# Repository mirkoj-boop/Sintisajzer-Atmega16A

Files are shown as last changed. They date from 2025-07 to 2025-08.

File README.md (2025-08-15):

# 🎹 Razvoj jednostavnog digitalno upravljanog sintisajzera temeljenog na mikroupravljaču ATmega16A

**** jednostavni PCB dizajn:
- **ATMEGA16-A** kao digitalni Oscilator
- an **LM386 preamplifier** pretpojačalo za 8 Ω zvučnik.

Dizajnirano jednostavno pojačalo za sintisajzer

1. Inicijaliziraj I2C komunikaciju
2. Inicijaliziraj tri MCP23008 čipa (postavi sve pinove kao ulaze)
3. Beskonačno ponavljaj:
   a. Pročitaj stanje tipki s prva tri MCP23008 čipa (8 tipki po čipu, ukupno 24)
   b. Inverzija očitanja (jer su tipke aktivne na LOW)
   c. Provjeri pritisnute tipke u sljedećem redoslijedu:
      - Za prvi čip (tipke 0-7):
        Ako je neka tipka pritisnuta, pošalji vrijednost note (notes[0-7]) na DAC i prekini
      - Ako nema pritisnutih tipki na prvom čipu, provjeri drugi čip (tipke 8-15):
        Ako je neka tipka pritisnuta26, pošalji vrijednost note (notes[8-15]) na DAC i prekini
      - Ako nema pritisnutih tipki na drugom čipu, provjeri treći čip (tipke 16-23):
        Ako je neka tipka pritisnuta, pošalji vrijednost note (notes[16-23]) na DAC i prekini
      - Ako nijedna tipka nije pritisnuta, postavi DAC na 0 (tišina)
   d. Pričekaj 10 ms prije sljedećeg očitavanja

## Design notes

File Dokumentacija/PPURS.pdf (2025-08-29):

### TEHNIČKO VELEUČILIŠTE U ZAGREBU

STRUČNI PRIJEDIPLOMSKI STUDIJ ELEKTROTEHNIKA

Mirko Jokić

# Razvoj jednostavnog digitalno upravljanog sintisajzera temeljenog na mikroupravljaču Atmega16A

Projektni Zadatak PPURS

Zagreb, Kolovoz 2025

## Sadržaj

Sadržaj
Uvod | 3
1.1 Odabir mikroupravljača za projektni zadatak | 4
2 Opis hardvera | 5
2.1 Implementacija predpojačala kroz LM386 | 6
2.2 MCP23008 I2C Port Expander | 7
2.3 1602 LCD 4-bitni ekran | 9
2.4 Kućište sinsajzera | 10
2.5 Troškovnik | 11
3 Programski Kod | 12
Zaključak | 13
Prilog | 14
Literatura | 20

Slike
Slika 1.1 Blok shema projekta | 3
Slika 2.1 Kicad shema MCP23008 24 pke | 5
Slika 2.2 Shema predpojačala | 6
Slika 2.4 Shema MCP23008 Port Expander | 7
Slika 2.5 PCB Editor shema 24 pke | 8
Slika 2.6 LCD ekran 4-bitno Serijski spojen | 9
Slika 2.7 Kućište Sinsajzera | 10
Slika 3 Flow Chart glavnog programskog koda | 12

Tablica
Tablica 1 Opis MCP23008 spojeva | 8
Tablica 2 Troškovnik | 11

## Uvod

Razvoj mikroupravljača i prateće digitalne elektronike omogućio je da se i složeni sustavi, poput glazbenih instrumenata, mogu realizirati jednostavno i pristupačno. Zahvaljujući svojoj fleksibilnosti, mogućnosti programiranja i količini opće programirljivih ulazno/izlazno jedinica na mikroupravljaču, omogućili smo jednostavnije projektiranje kopija modernih sintisajzera.
Naponski generiran oscilator i filter sada je lako zamijenjiv sa Digitalnim oscilatorom koji uzorkovanjem šalje signal analognom psintisajzera.
Cilj ovog rada je povezati digitalnu i analognu elektroniku kroz izradu jednostavnog digitalno upravljanog glazbenog sintisajzera. stav se temelji na mikroupravljaču Atmega16A-U, koji generira digitalne zapise tonova putem širinsko impulsne modulacije koji frekvencijskim odzivom preuzetim sa poljem koje sadrži tonove od C4 do B3 priprema za daljnu obradu.
Taj se signal dalje pojačava analognim pretpojačalom i dovodi na zvučnik. Ulazni sustav temelji se na tipkama povezanima preko I2C proširivača ulazno-izlaznih portova, čime se postiže jednostavan dizajn i omogućava korištenje većeg broja ulaza nego što ih mikroupravljač sam nudi.

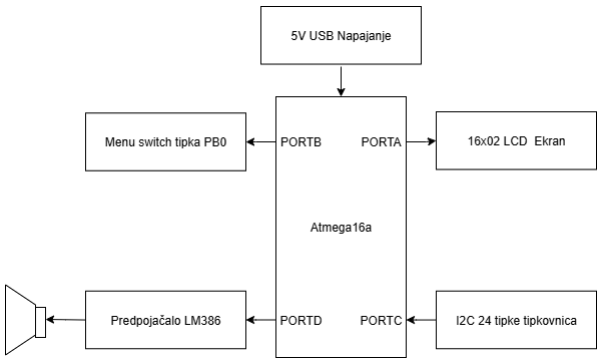
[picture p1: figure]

Slika 1.1 Blok shema projekta

## 1.1 Odabir mikroupravljača za projektni zadatak

Baza samog kontrolera je mikorupravljač Atmel ATMEGA 328-PU. Kontroler ima funkciju Digitalnog naponskog oscilatora koji stvara signal pripremljen za ostatak mreže. Opremljen je serijskom komunikacijom kojom je spušten C programski kod i kojim je naknadno spojen 1602 LCD module. Ostatak mreže napajan je I2C protokolom. Sam mikroupravljač spojen je 220V AC adapterom na 5V DC koji dijeli na ostatak komponen.

Prema prethodno izrađenom blok dijagramu, izrađena je električna shema kontrolera koja obuhvaća sve elemente potrebne za povezivanje senzora i aktuatora odnosno uređaja.
Kod dizajna tiskane pločice elementi se automatski iz sheme, prenose na tiskanu pločicu koji se ručno razmještaju prema potrebama s obzirom na izvedbu kućišta kontrolera. Sami dizajn osim što obuhvaća razmještaj komponenti i vodova, obuhvaća definiranje debljina vodova, razmake između vodova, definiranje Via između slojeva i rupa za montažu.

Tehnička specifikacija mikroupravljača Atmel ATmega16A-PU

- Arhitektura: 8-bitni RISC mikroupravljač
- Taktni generator: do 16 MHz (u ovom sustavu: 16 MHz kvarc)
- Radni napon: 2.7 V do 5.5 V (1.8 V – 5.5 V u „low frequency” načinu, do 8 MHz)
- Flash memorija: 16 KB (od čega do 512 B može bi rezervirano za bootloader)
- SRAM: 1 KB
- EEPROM: 512 B
- Ulazno-izlazni pinovi: 32 programabilna I/O pina
- ADC kanali: 8 (10-bitni A/D pretvarač)
- Komunikacija: UART, SPI, I²C (TWI)
- Timeri: dva 8-bitna i jedan 16-bitni mer
- Potrošnja: pično par mA u akvnom načinu rada, < 1 µA u power-down modu
- Paket: PDIP-40 (u ovom projektu)

## 2 Opis hardvera

Korisničko sučelje sintisajzera realizirano je pomoću 24 tipke na PCB ploči sa SMD komponentama projektirano u Kicad 9.0 programu. Za proširenje dostupnih ulaza spojena su 3 MCP23008 PORT Expander-a, putem I2C protokola. Ovom tehnikom omogućeno je najbrže komercijalno dostupno očitanje stanja svih tipki 100 kHZ.

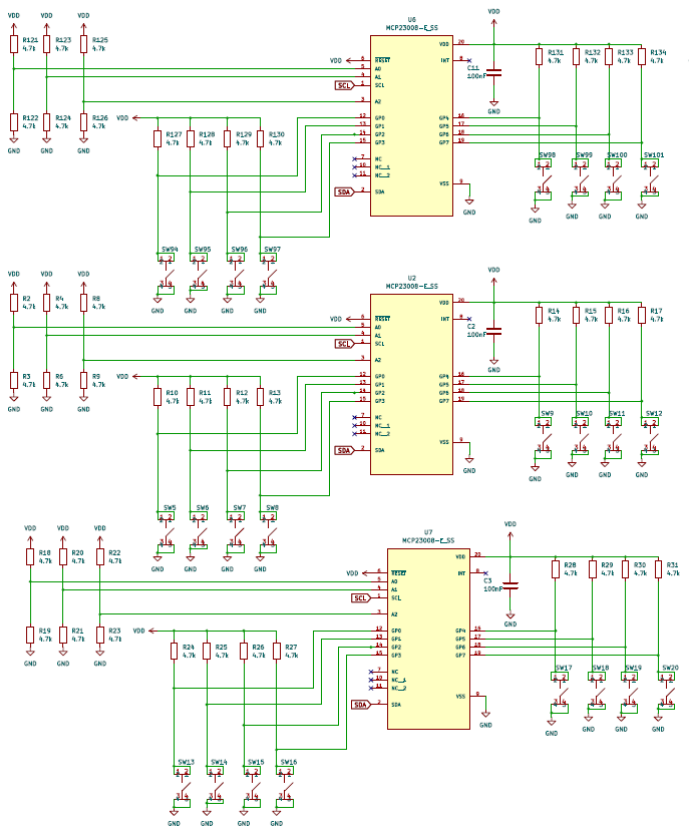
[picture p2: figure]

Slika 2.1 Kicad shema MCP23008 24 pke

### 2.1 Implementacija predpojačala kroz LM386

LM386 je predpojačalo klase AB dizajnirano za male izlazne snage. Interni Gain iznosi 20, a postavljen je 200, spajanjem elektrolitskog kondenzatora u vrijednosti od 10 µF, između pinova 1 i 8.
Ulazni pinovi mjere se u odnosu na masu, dakle referentan napon oko koje siječe audio signal je 0 V. Čip je napajan prema 5 V a referencu dobija sa Atmega16A PortD pina PD7, ispred kojeg je stavljen 10 KΩ potenciometar.

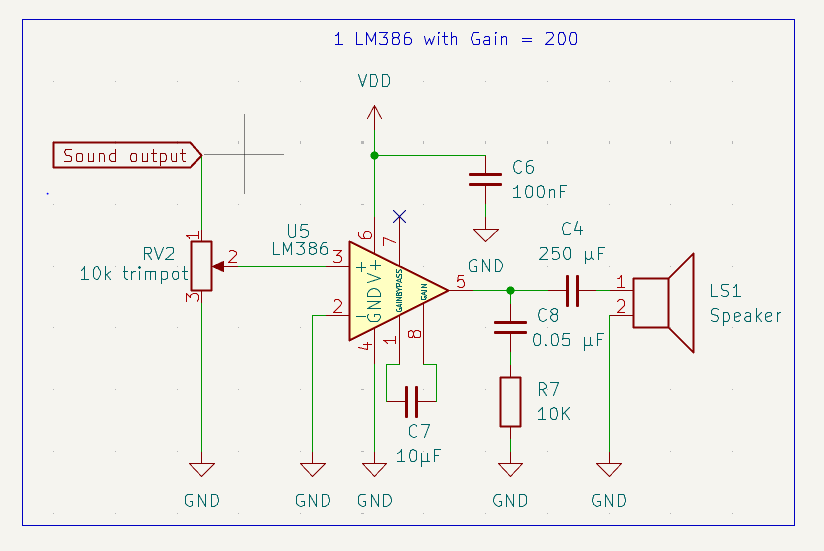
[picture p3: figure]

Slika 2.2 Shema predpojačala

Predpojačalo upravlja 8Ω zvučnikom snage 0.5 W, zbog čega je idealan za ovakve primjene zbog male potrošnje energije i dobrog omjera kvalitete pojačanog signala i učinkovitosti, bez značajnih gubitaka u struji i pregrijavanja komponente.

### 2.2 MCP23008 I2C Port Expander

MCP23008 je ekspanzijski sklop koji služi za proširenje broja ulazno/izlaznih jedinica mikrokontrolera koristeći I2C(TWI) sabirnicu. Sastoji se od 8 GPIO proširivih ulaza/izlaza i 3 adresna pina pomoću kojih se određuje adresa modula na sabirnici.

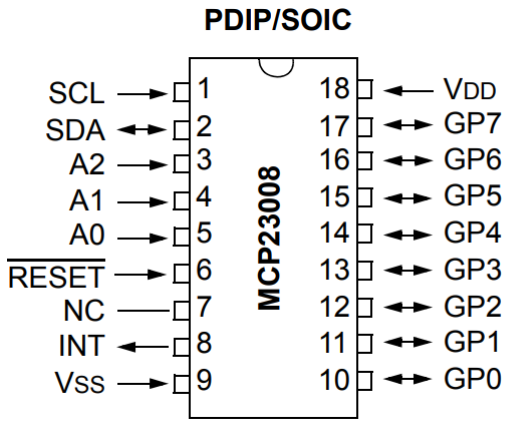
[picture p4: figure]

Slika Slika 24 .3Shema MCP23008 Port Expander Shema MCP23008 Port Expander

Pin | Naziv | Opis
1 | SCL | Takt
6 | RESET | Reset
9 | VSS | Napajanje
2 | SDA | Serijsko slanje podatka
7 | NC | Nema Konektora
3-5 | A1-A3 | Adresni pinovi
8 | INT | Interrupt izlaz
10-18 | GPIO | I/O tipka

Tablica 1 Opis MCP23008 spojeva

U praktičnoj primjeni često se preferira konfiguracija u kojoj su pinovi u visokom logičkom stanju (pull-up), a prelaze u nisko stanje (LOW) prilikom aktivacije tipke. Takva konfiguracija osigurava stabilniji rad i smanjuje osjetljivost sustava na elektromagnetske smetnje.
Master mikrokontroler ATMEGA16A komunicira s MCP23008 po vaki od triju adresnih pinova (A0–A2) može biti spojen na izvor napajanja (logička jedinica) ili na masu (logička nula) koju kasnije pomiče zavisno od čitanja/pisanja stanja. Na taj način moguće je formirati osam različitih adresa uređaja u rasponu od 0x20 do 0x27. U ovom projektu korištene su adrese 0x21, 0x22 i 0x23, što omogućuje spajanje i neovisno adresiranje triju MCP23008 modula na istoj I2C sabirnici.

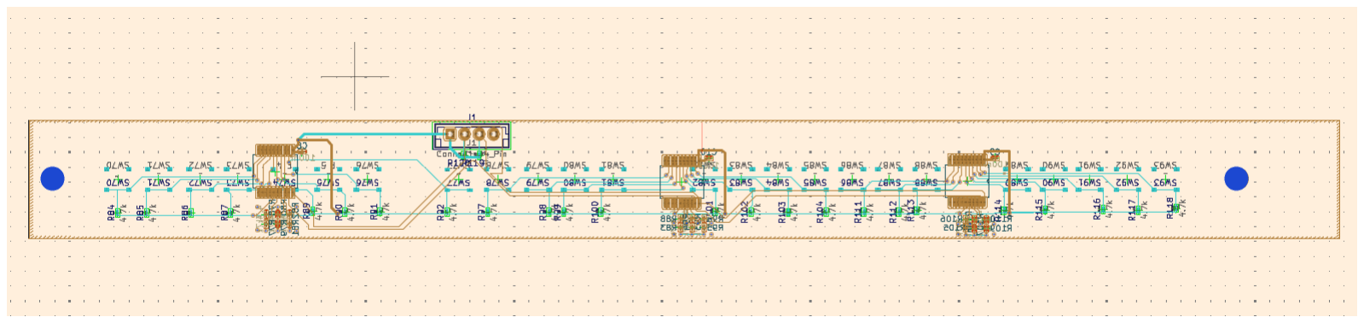
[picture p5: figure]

Slika 2.4 PCB Editor shema 24 pke

### 2.3 1602 LCD 4-bitni ekran

U projektu je korišten standardni LCD 16x2 zaslon temeljen na HD44780 kontroleru. Ovakav zaslon prikazuje 16 znakova u dva retka, a komunikacija je ostvarena u 4-bitnom načinu rada. U takvom načinu rada, podaci se šalju u dva dijela tzv. Nibble. Ponajprije se šalje viši, a zatim niži polubajt(Nibble). Važno je napomenuti kako u ovom načinu rada ekran je obavezno spojen D4- D7, a ne od početka(D0-D3) kako bi znao kontroler poslati 4-bitnu, a ne 8-bitnu komunikaciju. LCD zaslon analogno upravlja pozadinskim osvijetljenjemi osvijetljenjem znakova. Važno je stoga ispravno spojiti LED+ i LED-, tj, između obavezno postaviti otpornik, u ovom slučaju 560 Ω. Svijetlinu znakova regulira trimmer potenciometar 10 KΩ, odabran zbog veličine koja stane na pločicu.

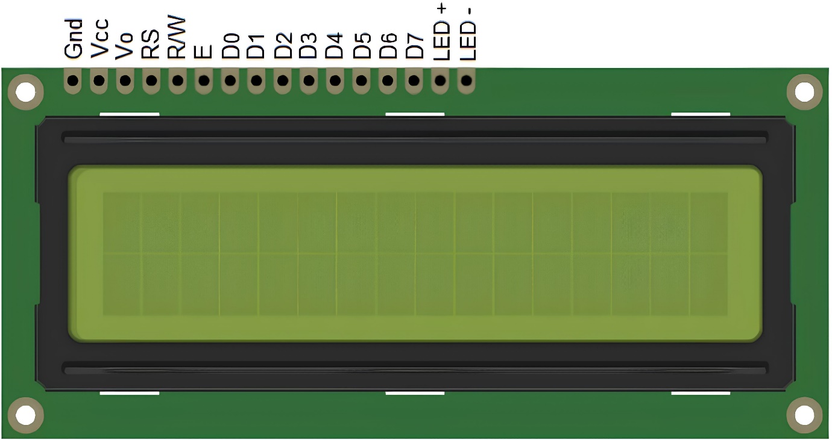
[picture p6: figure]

Slika 2.5 LCD ekran 4-bitno Serijski spojen

### 2.4 Kućište sinsajzera

Kućište uređaja prvo je osmišljeno i modelirano u programu AutoCAD 2025, a zam je prenijeto u SolidWorks 2020, gdje su izrađeni BOM (Bill of Materials) i STL datoteke potrebne za 3D ispis.

Za izradu kućišta korišten je 3D printer Bambu Lab X1 Carbon, a proces ispisa trajao je približno 4 sata. Materijal korišten za ispis bio je ASA filament (bijeli), odabran zbog svoje čvrstoće i otpornos na vanjske uvjete.

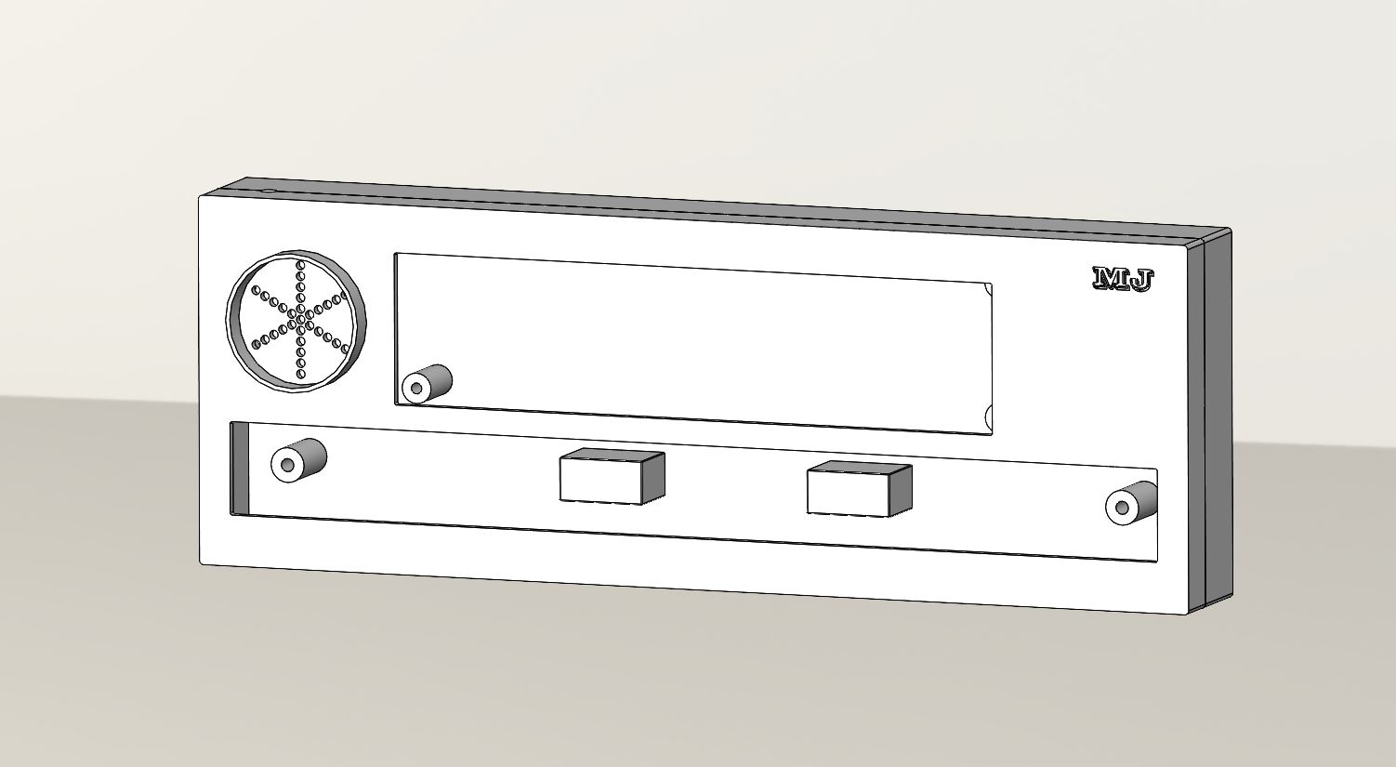
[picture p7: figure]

Slika 2.6 Kućište Sinsajzera

Prva iteracija imala je nekoliko problema:
- Poklopac je krivo isprintan i zvučnik se ne drži na mjestu
- Dimenzije su bile pogrešne, bio je predubok
- Donja strana je imala značajne deformacije

Konačna verzija kućišta pokazala se zadovoljavajuće kvalitete i funkcionalnos te estetski odgovara namjeni sinsajzera.

### 2.5 Troškovnik

Cijena uređaja sastoji se od maloprodajne cijene komponenti na tržištu i cijene izrade. Mjerni uređaji poput osciloskopa, lemilice, računala, 3d printera e računaju se u materijalne troškove, već se uračunavaju u cijenu uloženog rada.
Komponente | Cijena u €
Atmega16a | 2.85 €
LCD ekran | 3.15 €
PCB pločica | 39 €
Bijeli filament za 3d printer | 22.90 €
Tipke | 12.72 €
Lm386 | 1.31 €
Otpornici i kondenzatori | 1.30 €
Protoboard | 1.90 €
Ukupno | 85.13 €
Tablica 2 Troškovnik

Trošak izrade bez uračunah protopa iznosi 85.13 €, zajedno sa pokušajima i tesranjima prelazi 100 €.
Projekranje, izrada, narudžba i lemljenje iznosi 8 € po satu, za dva radna tjedna 8h rada = 640 €

## 3 Programski Kod

Programski kod napisan je u programskom okruženju Microchip studio. Razvojno okruženje omogućuje kvalitetan linker i toolchain #include <avr/io.h>. Taj header file definira sve registre i bitove potrebne za konfiguraciju i upravljanje svim protokolima i sučeljima koje se mogu ostvariti na Atmega mikroupravljaču.
Bez ovog zaglavlja, program ne bi mogao direktno pristupiti registrima i konfigurirati pinove ili periferije mikrokontrolera.
U glavnom programskom kodu Atmega16a poziva sve periferije sukladno dogovorenom protokolu. Rad je sastavljen od 3 protokola, one wire toggle za stanje tipke PB0, I2C za 24 tipke koje sviraju i 4 bitna serijska komunikacija za LCD ekran.
Sve to povezano je kroz header datoteke koje pozivaju funkcije objasnjene u sklodnim kodovima unutar istog projekta.

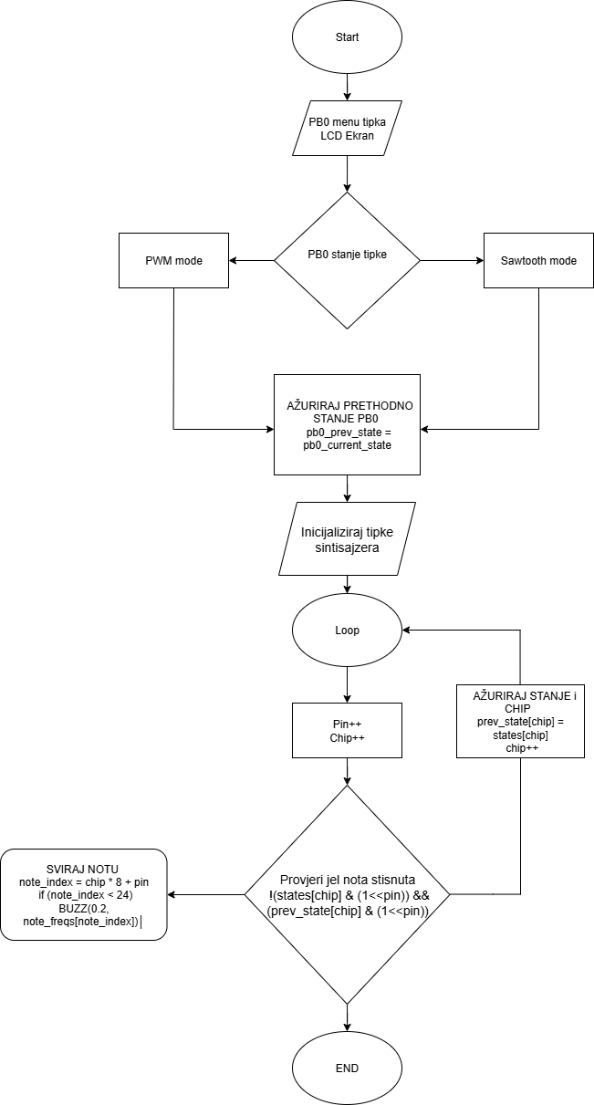
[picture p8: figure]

Slika 3 Flow Chart glavnog programskog koda

## Zaključak

U ovom projektnom zadatku uspješno je realiziran jednostavan digitalno upravljani sintisajzer temeljen na mikroupravljaču Atmega16A. Projekt je pokazao kako se kombinacijom digitalne i analogne elektronike može ostvariti funkcionalan glazbeni instrument pristupačne cijene i relativno jednostavne izvedbe.
Kroz implementaciju MCP23008 I2C port expandera omogućeno je proširenje broja ulaza te povezivanje 24 tipke, čime je ostvareno korisničko sučelje instrumenta. Generirani signal obrađen je i pojačan pomoću predpojačala temeljenog na LM386, a izlazni zvuk dobiven je putem zvučnika. Dodatno, korišten je LCD zaslon 16x2 za prikaz informacija, što doprinosi preglednosti sustava. Posebna pažnja posvećena je i mehaničkom dijelu – kućište je izrađeno 3D printanje, čime je postignuta funkcionalna i estetski prihvatljiva izvedba.
Projektu nedostaju brzina i sigurnost izvedbe. Sigurnost koda temeljena je na testiranju usart komunikacijom kojom je ostvaren predpregled nadolazećih funkcija I protokola.

Kao smjer budućeg razvoja, moguće je razmotriti promjenu mikroupravljača, kvalitetniji error check, više vizualnih signala i kvalitetnija izrada.

## Prilog

U prilogu se nalazi main kod programa i električne sheme sklopa

### include "AVR lib/AVR_lib.h" #include <avr/io.h> #include <util/delay.h> #include "I2C/i2c.h" #include "LCD/lcd.h" #define MCP23008_ADDR1 0x21 #define MCP23008_ADDR2 0x22 #define MCP23008_ADDR3 0x23

### #define IODIR 0x00

#define GPPU | 0x06 // Pull-up registar

#define GPIO | 0x09

### static const int note_freqs[24] = {

262, 277, 294, 311, 330, 349, 370, 392, 415, 440, 466, 494,

### // C4 do B4

523, 554, 587, 622, 659, 698, 740, 784, 831, 880, 932, 988

### // C5 do B5

};

uint8_t display_mode = 0;
uint8_t pb0_prev_state = 1;

### void mcp23008_init(uint8_t addr)

{
uint8_t write_addr = addr << 1;

### if (i2c_start(write_addr) != 0) {

return;
}
i2c_write(IODIR);
i2c_write(0xFF);
i2c_stop();
if (i2c_start(write_addr) != 0) return; i2c_write(GPPU);
i2c_write(0xFF);
i2c_stop();
}

### uint8_t mcp23008_read(uint8_t addr) {

uint8_t write_addr = addr << 1;
uint8_t read_addr = write_addr | 0x01;

i2c_start(write_addr);
i2c_write(GPIO);
i2c_rep_start(read_addr);
uint8_t data = i2c_read_nack(); i2c_stop();
return data;
}

### void inicijalizacija() {

input_port(DDRB, PB0);
set_port(PORTB, PB0, 1);

### lcd_init(); // inicijalizacija lcd displeja

}

### void update_display() {

lcd_clrscr();
lcd_home();

### if (display_mode == 0) {

lcd_print("PWM");

### } else {

lcd_print("sawtooth");
}
}

### int main(void) {

inicijalizacija();
lcd_clrscr();
lcd_home();

lcd_print("Welcome");
_delay_ms(1000);

update_display();

SAWTOOTH(0.2, 440);
i2c_init(100000);

mcp23008_init(MCP23008_ADDR1); mcp23008_init(MCP23008_ADDR2); mcp23008_init(MCP23008_ADDR3); _delay_ms(100);
SAWTOOTH(0.1, 523);
_delay_ms(100);
SAWTOOTH(0.1, 659);
_delay_ms(100);
SAWTOOTH(0.1, 784);

uint8_t prev_state[3] = {0xFF, 0xFF, 0xFF};

### while (1) {

uint8_t pb0_current_state = get_pin(PINB, PB0);

### if (pb0_current_state == 0 && pb0_prev_state == 1) {

display_mode = !display_mode; update_display();
BUZZ(0.1, 880);
_delay_ms(200);
}

pb0_prev_state = pb0_current_state;

### uint8_t states[3] = {

mcp23008_read(MCP23008_ADDR1), mcp23008_read(MCP23008_ADDR2),

### mcp23008_read(MCP23008_ADDR3)

};

### for (uint8_t chip = 0; chip < 3; chip++) { for (uint8_t pin = 0; pin < 8; pin++) { if (!(states[chip] & (1 << pin)) && (prev_state[chip] & (1 << pin))) {

uint8_t note_index = chip * 8 + pin;

### if (note_index < 24) {

BUZZ(0.2, note_freqs[note_index]); }
}
}
prev_state[chip] = states[chip]; }
_delay_ms(50);
}
return 0;
}

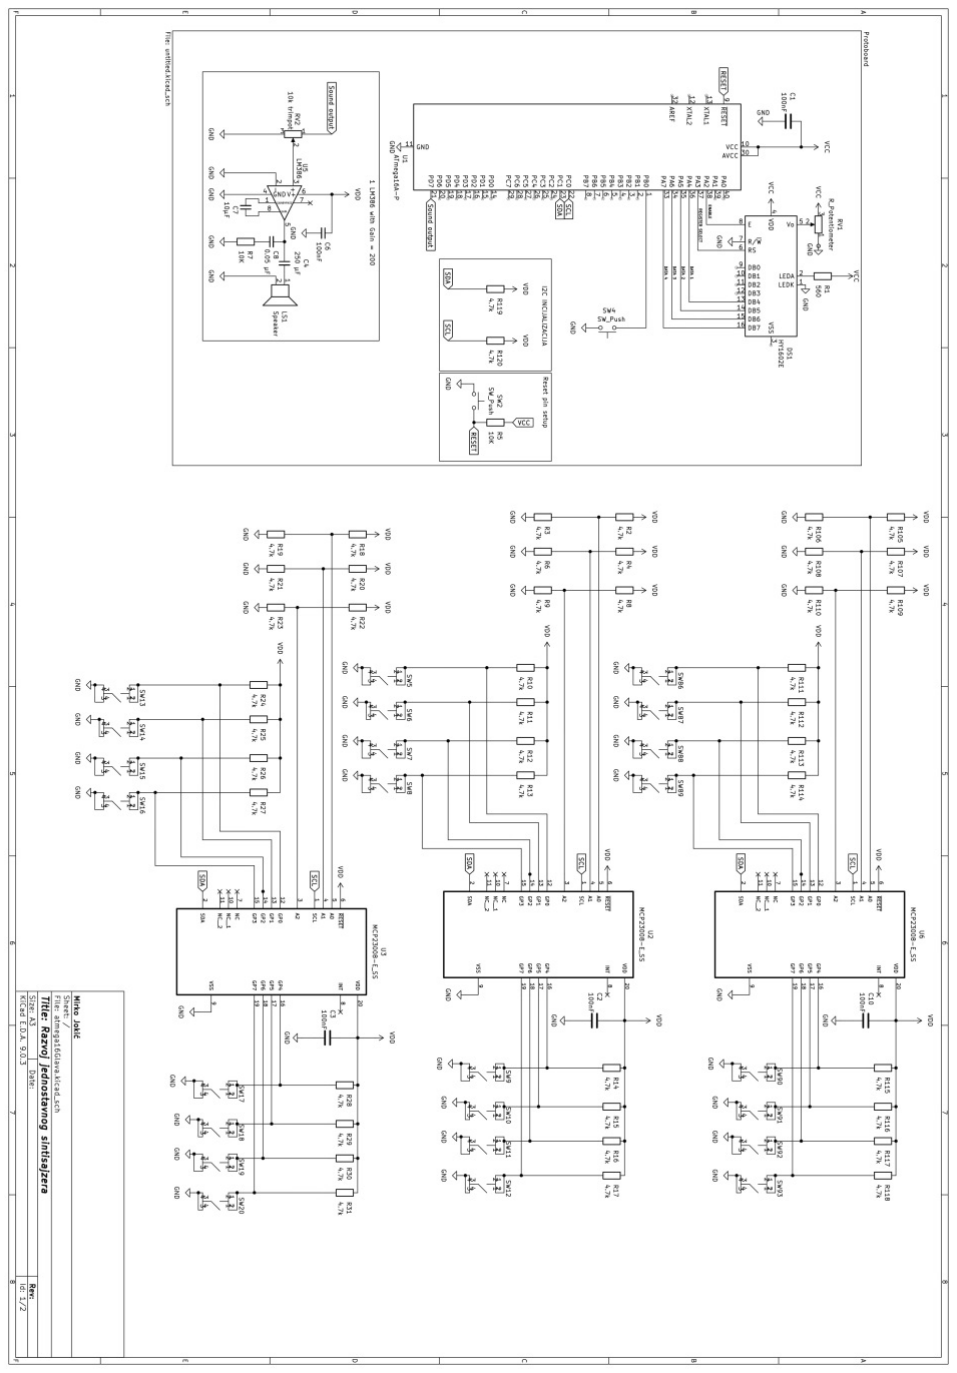
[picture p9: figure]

## Literatura

[1] Zoran Vrhovski, Marko Miletić: Mikroračunala.
[2] Vatroslav Zuppa Bakša, mag. ing. el. techn. inf.: Programiranje v2, Zagreb, 2021.
[3] Paul Horowitz, Winfield Hill: The Art of Electronics.
[4] Blog Poly Nomial: Creating High-Quality Electronics Schematics, 2025, link (https://blog.poly.nomial.co.uk/2025-08-10-creating-high-quality-electronics-schematics.html)
[5] Adam Tornhill: Patterns in C, PDF link (https://www.adamtornhill.com/Patterns%20in%20C%201.pdf?utm_source=chatgpt.com)
[6] Željko Stojanović: Analogni sklopovi – radni materijal, 2006.

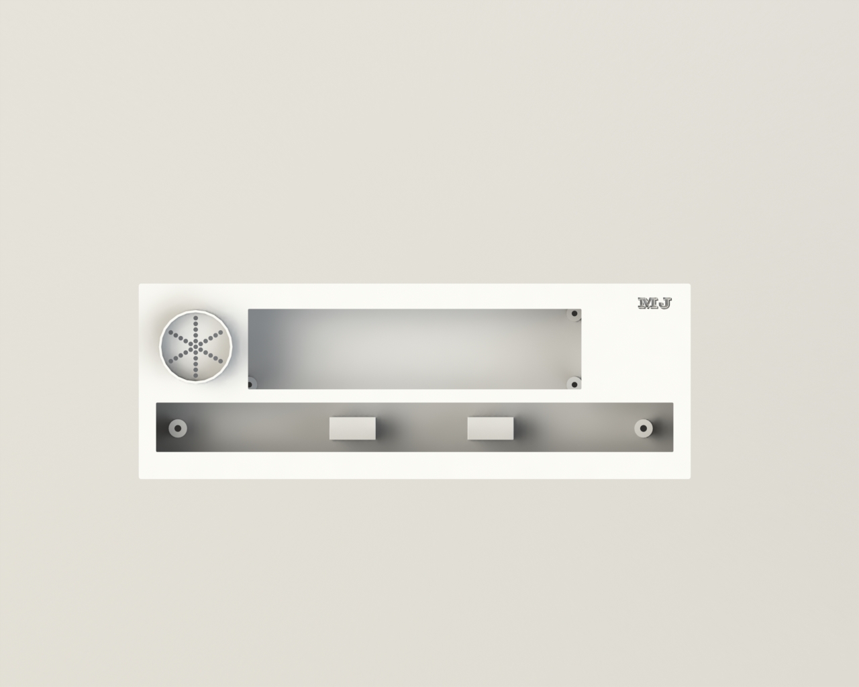
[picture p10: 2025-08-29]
HARDWARE/Kutija2 (1).JPG

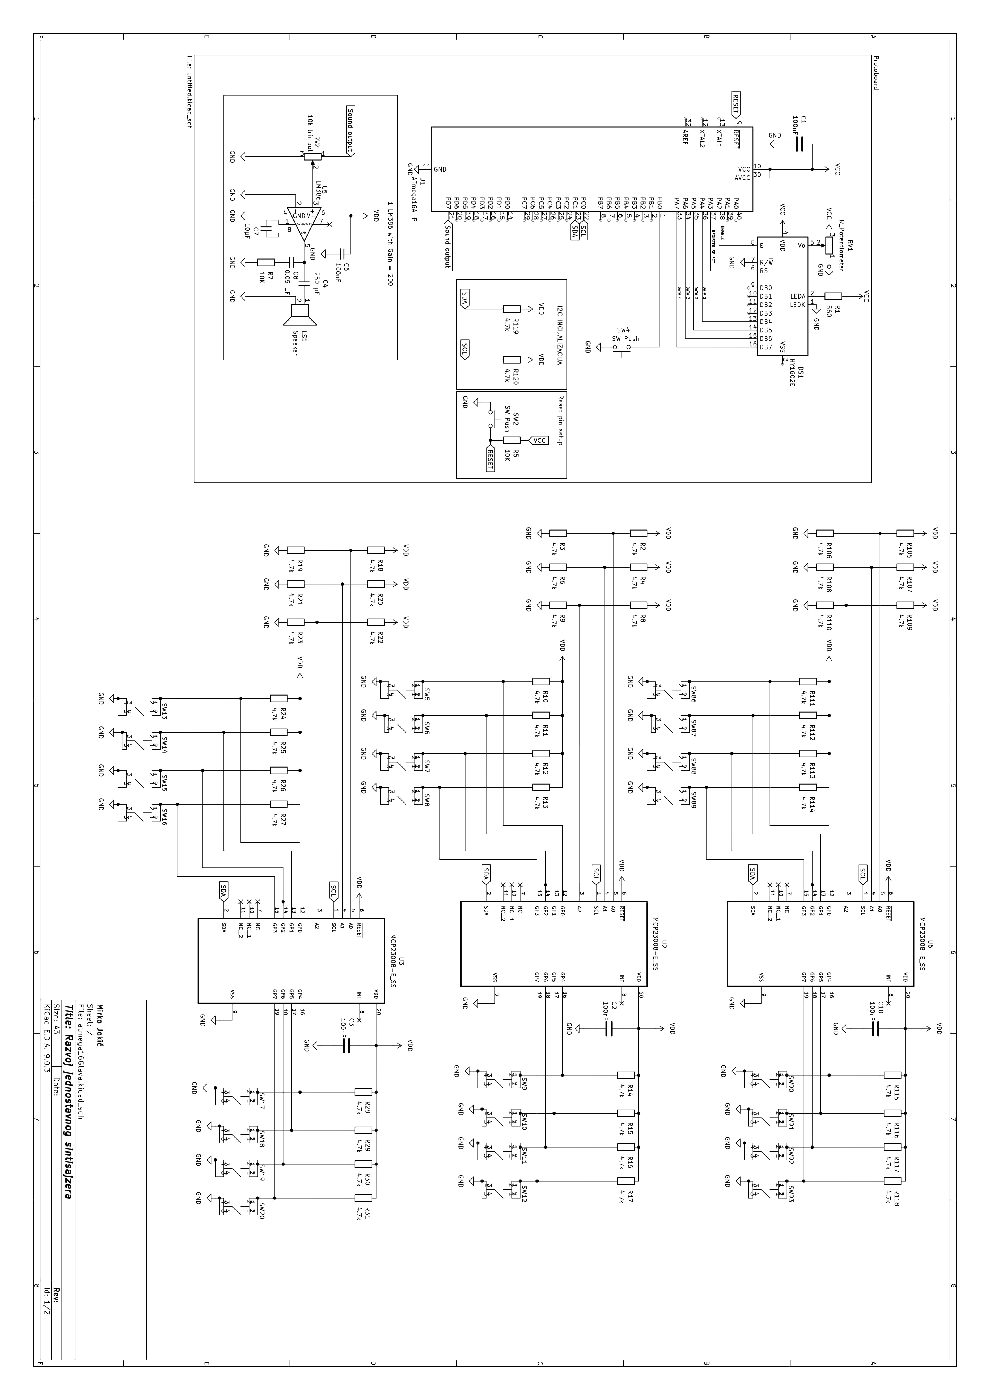
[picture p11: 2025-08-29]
HARDWARE/Shema Uređaja Sintisajzer_page-0001 (1).jpg

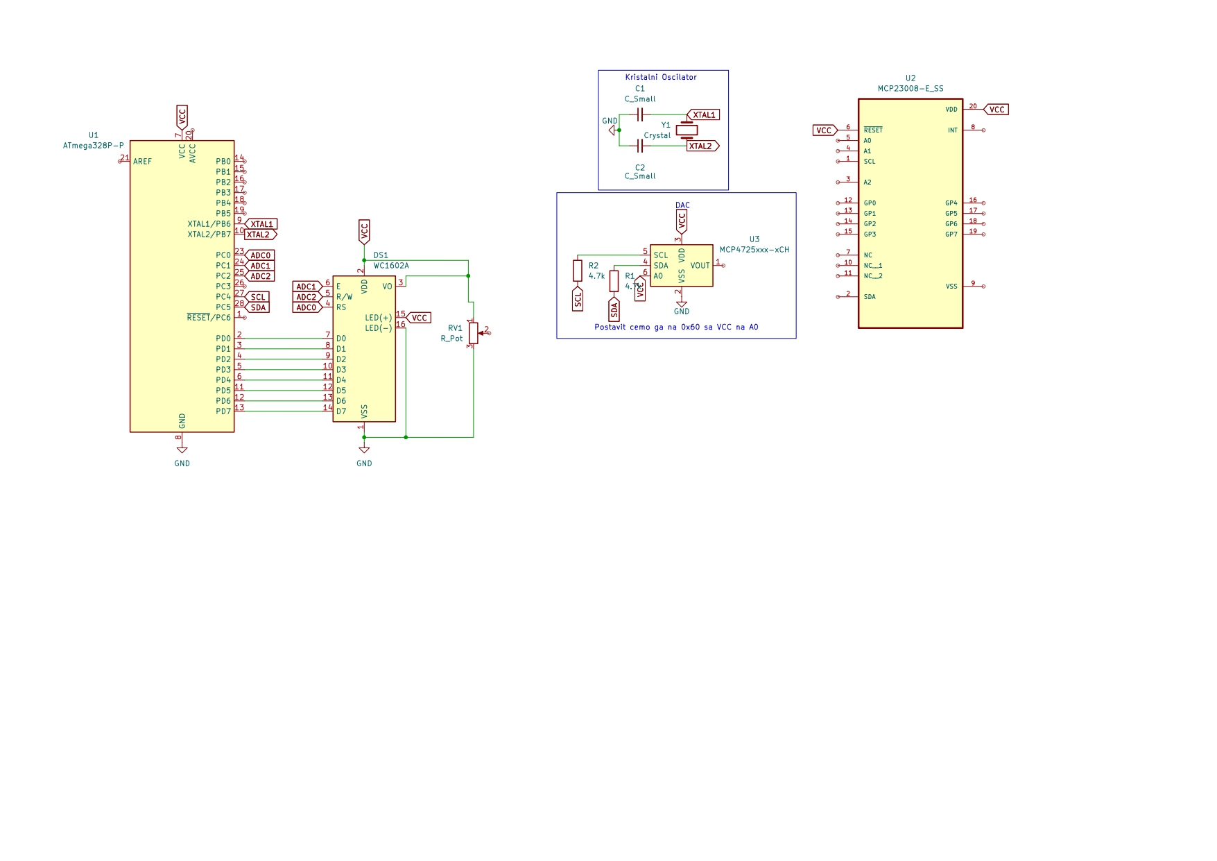
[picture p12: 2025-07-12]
Glavna Pločica/verzija pločice 0.1.jpg

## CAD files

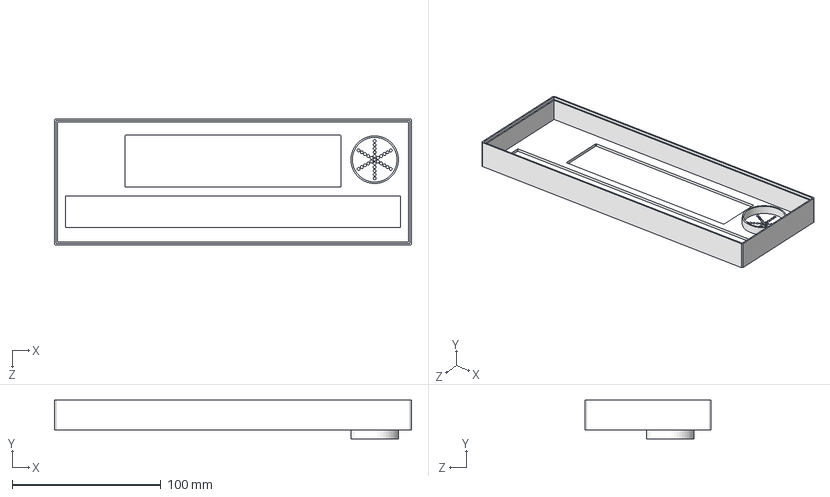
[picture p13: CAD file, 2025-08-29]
HARDWARE/Kućište Sintisajzera/gornja_strana.STEP
240.0 x 26.0 x 85.0 mm

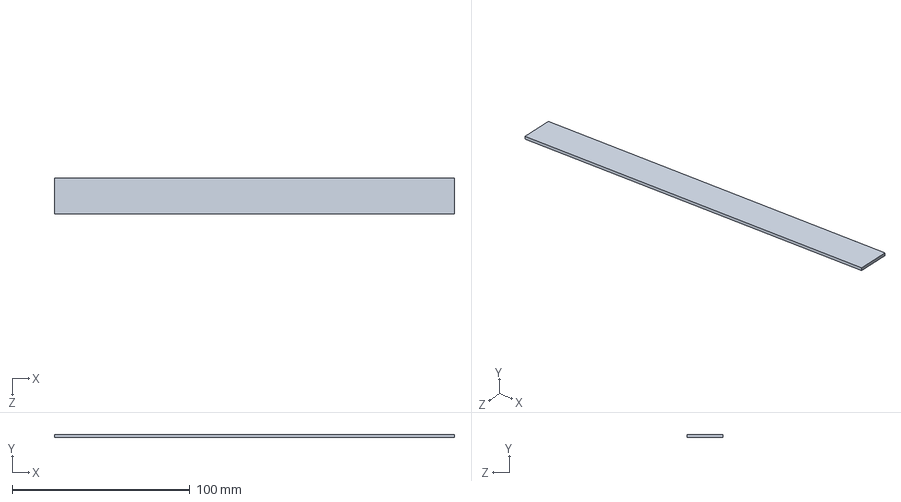
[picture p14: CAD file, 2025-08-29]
HARDWARE/Kućište Sintisajzera/pcb1.SLDPRT
225.0 x 1.70 x 20.0 mm

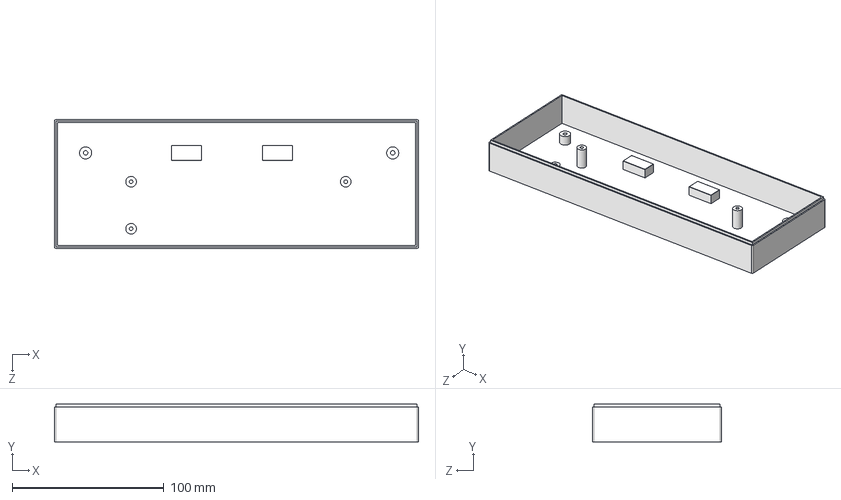
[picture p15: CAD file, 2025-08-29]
HARDWARE/Kućište Sintisajzera/donja_strana.STEP
240.0 x 25.0 x 85.0 mm

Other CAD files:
HARDWARE/Kućište Sintisajzera/donja_strana.SLDPRT
HARDWARE/Kućište Sintisajzera/gornja_strana.SLDPRT

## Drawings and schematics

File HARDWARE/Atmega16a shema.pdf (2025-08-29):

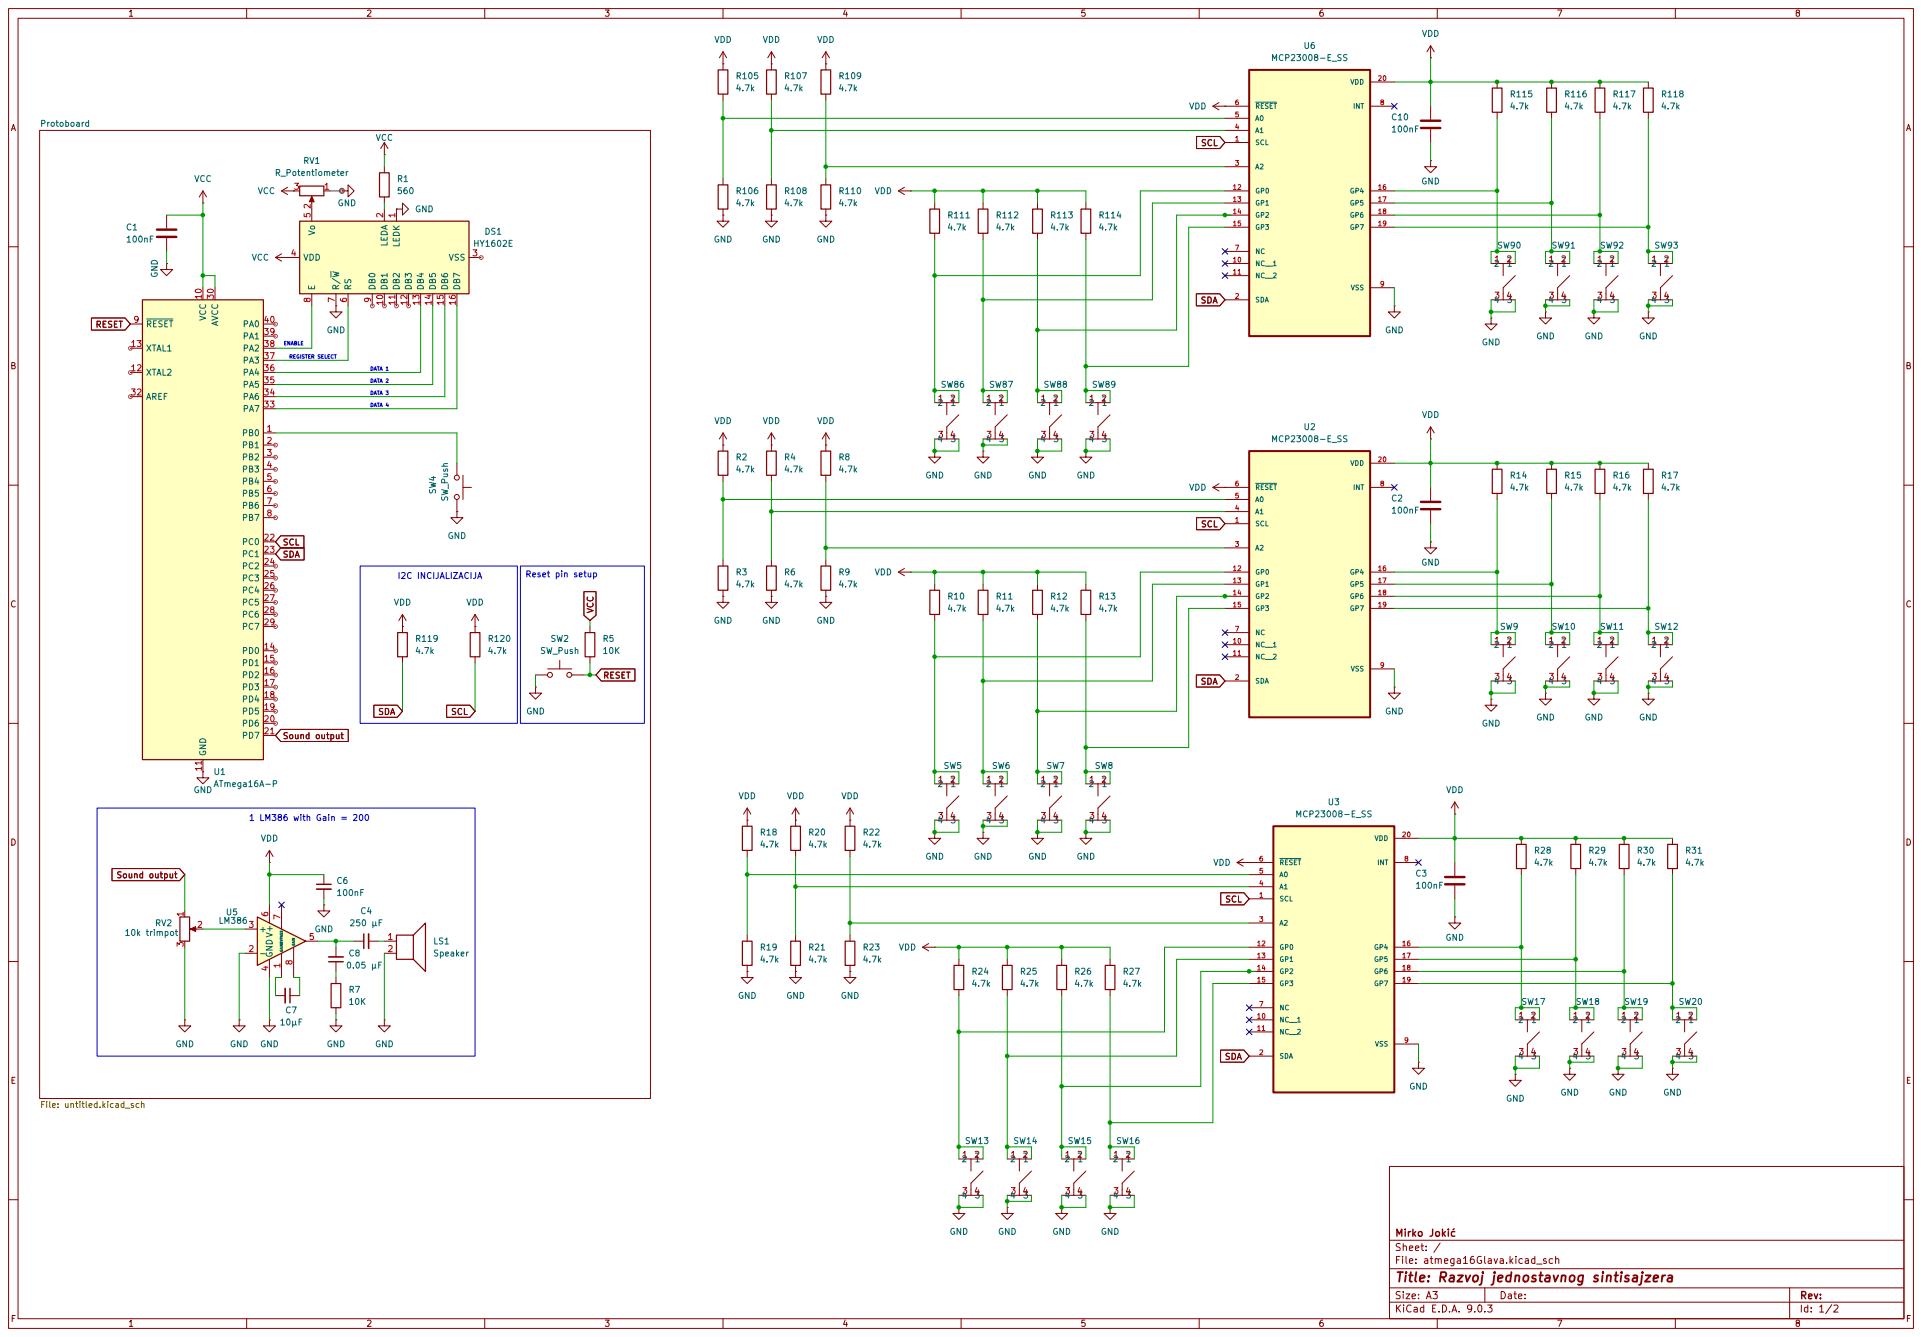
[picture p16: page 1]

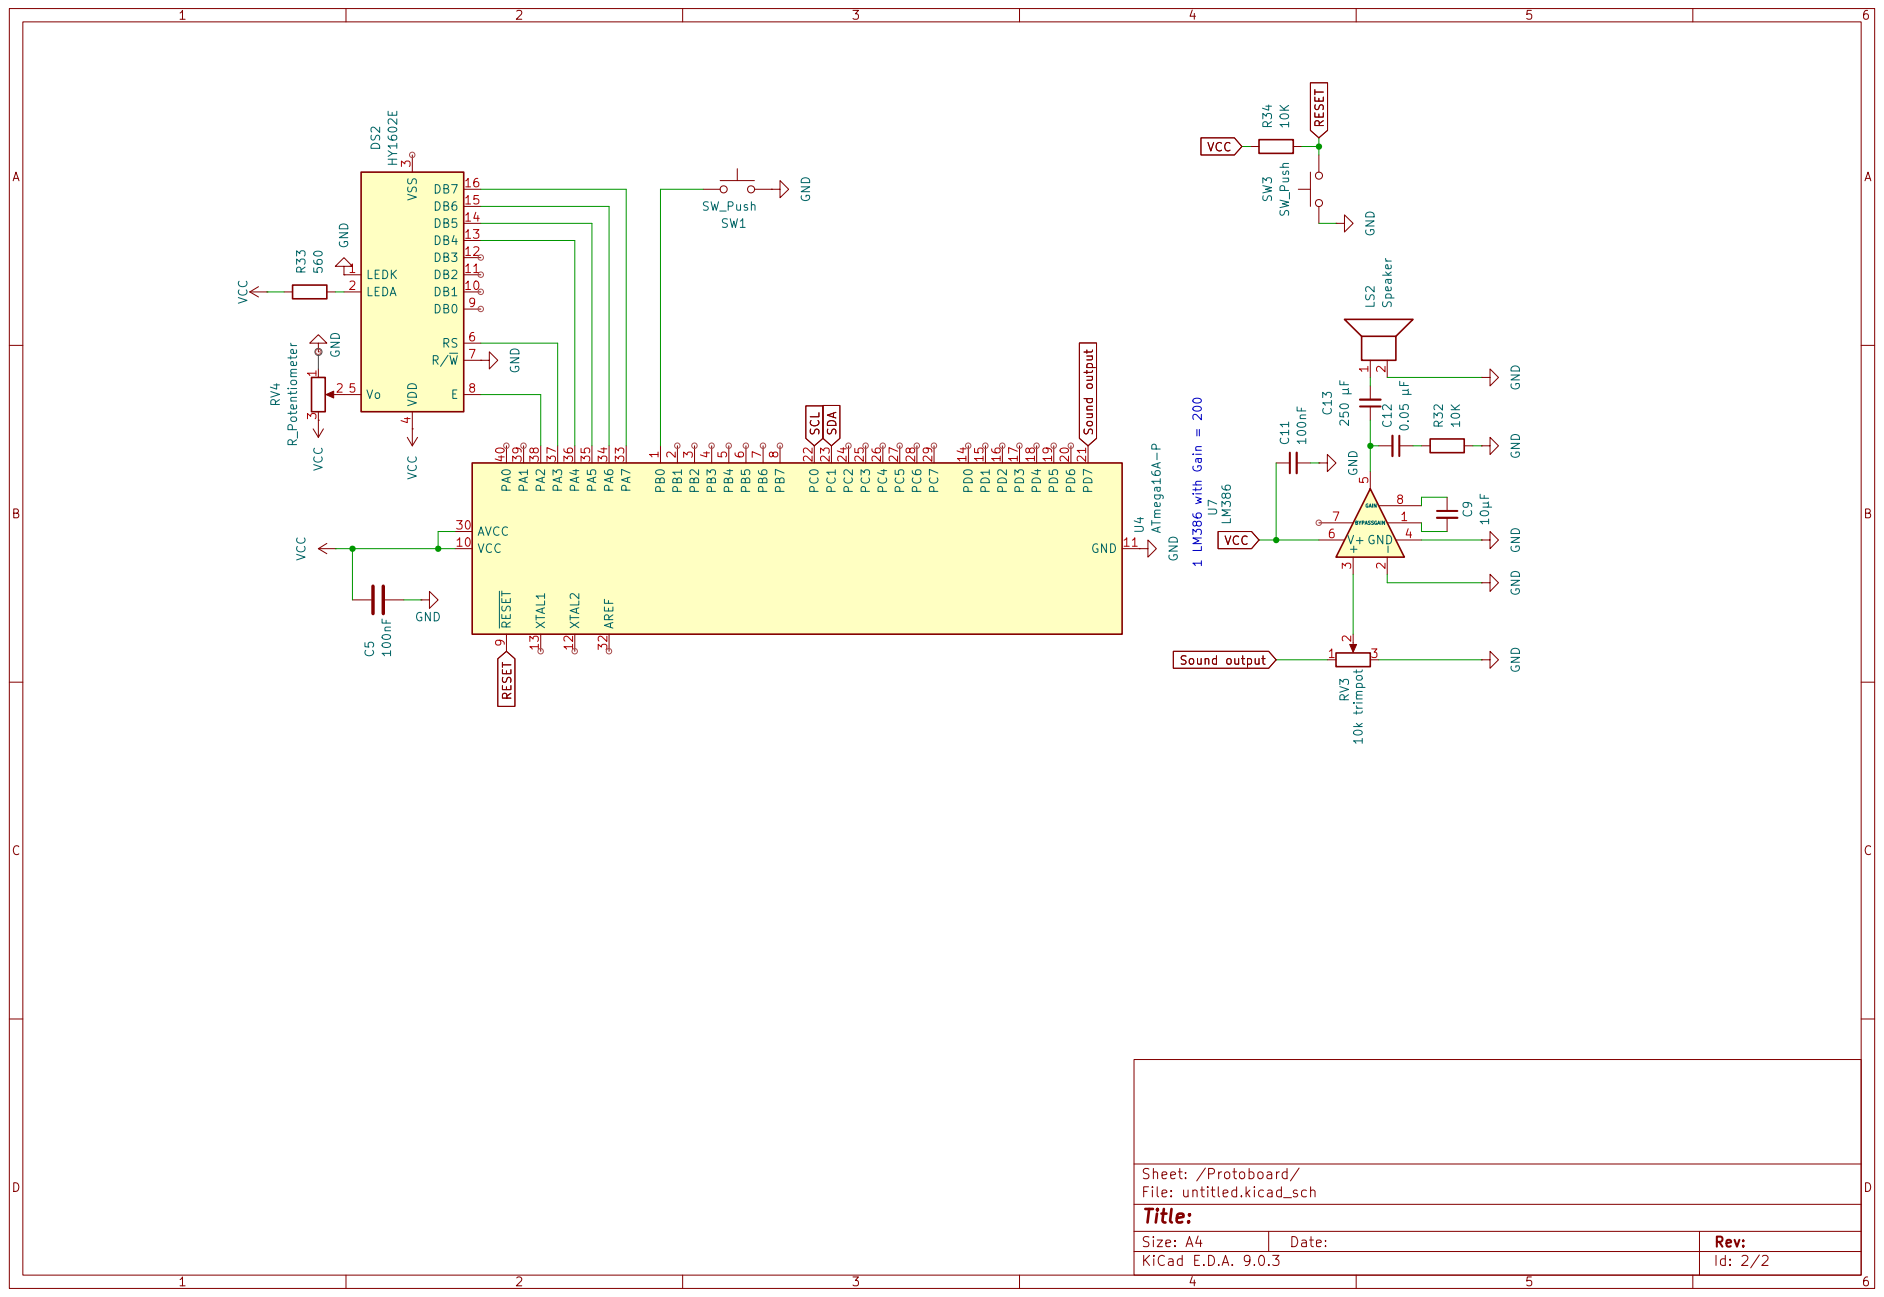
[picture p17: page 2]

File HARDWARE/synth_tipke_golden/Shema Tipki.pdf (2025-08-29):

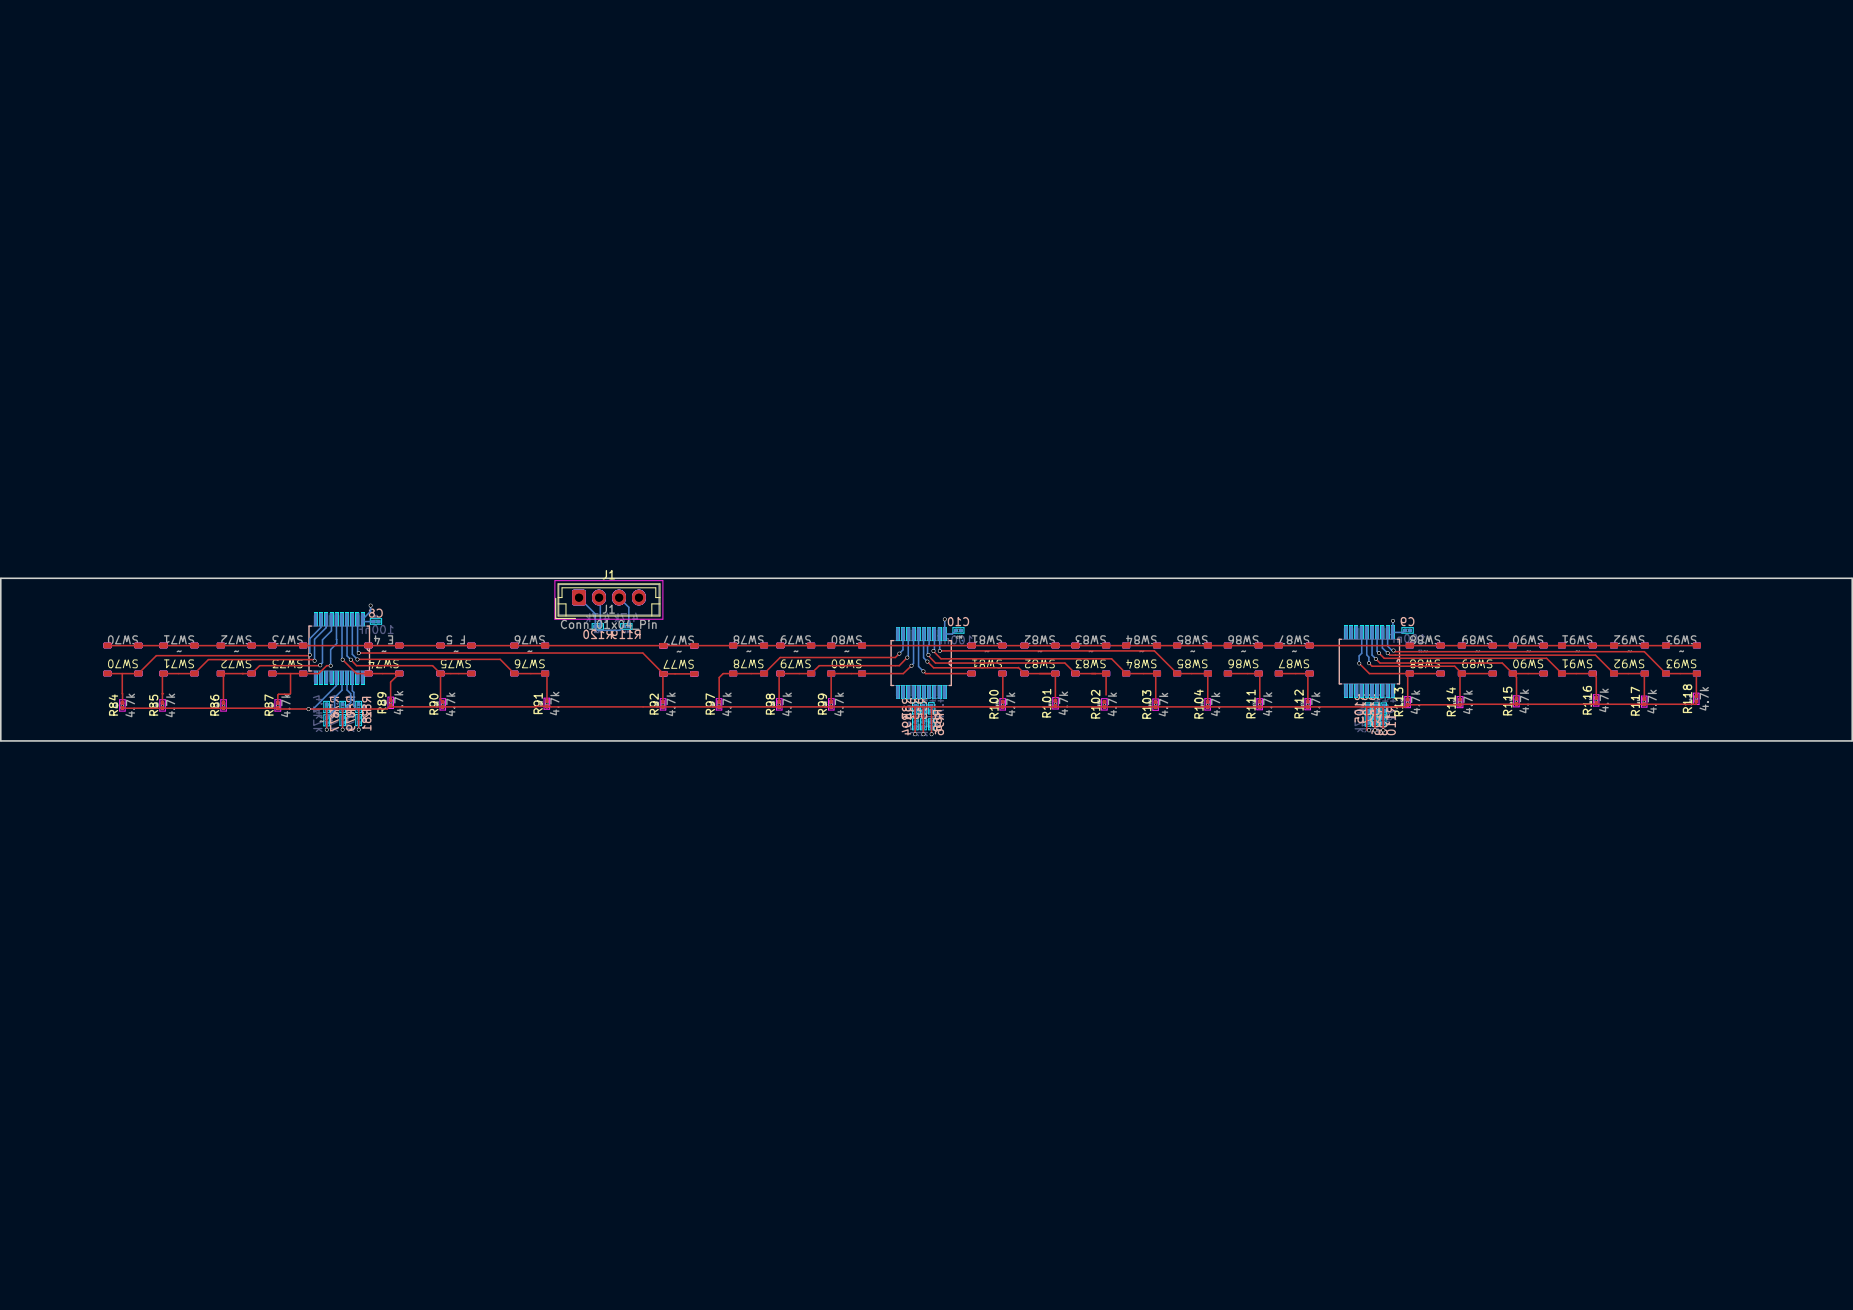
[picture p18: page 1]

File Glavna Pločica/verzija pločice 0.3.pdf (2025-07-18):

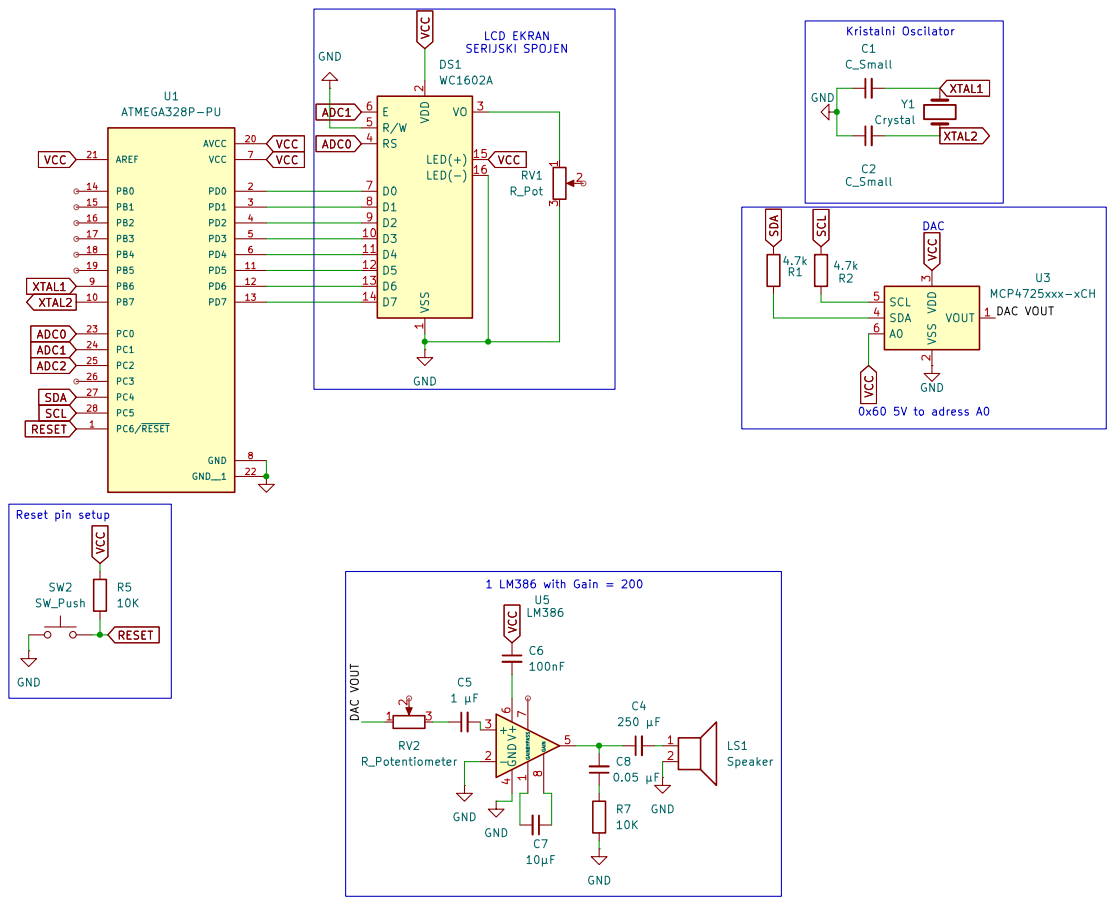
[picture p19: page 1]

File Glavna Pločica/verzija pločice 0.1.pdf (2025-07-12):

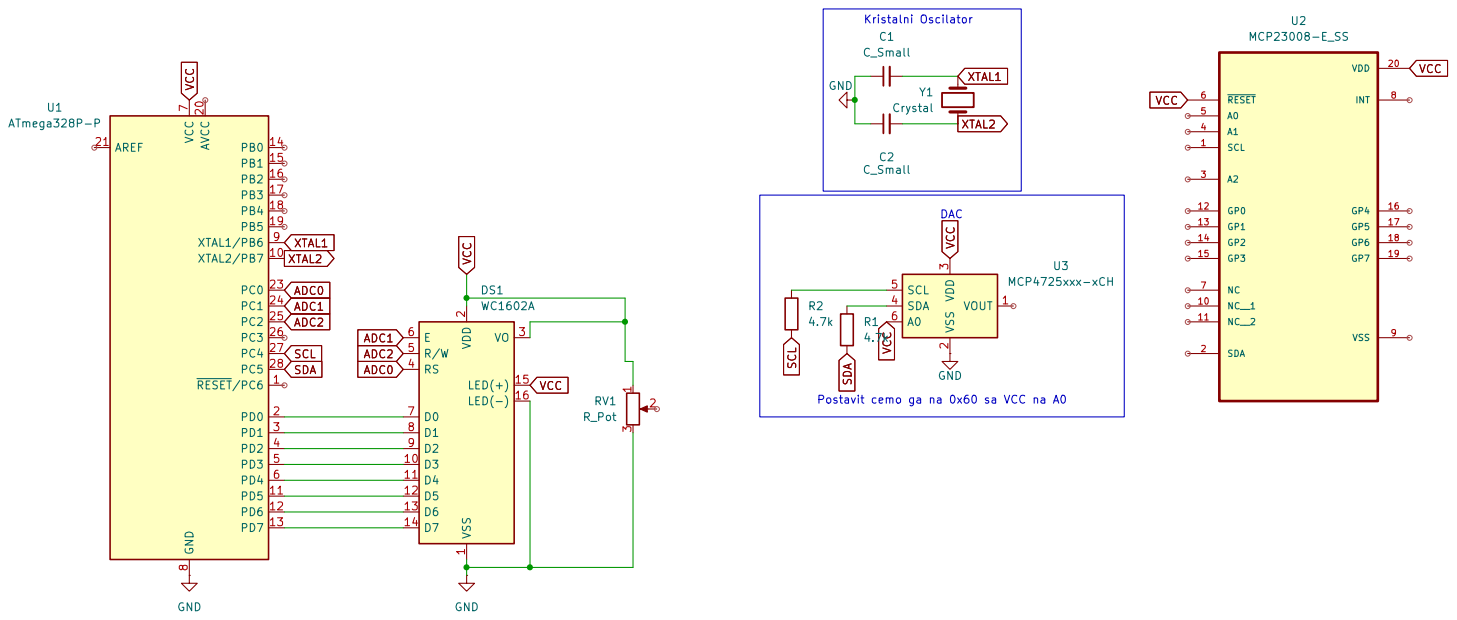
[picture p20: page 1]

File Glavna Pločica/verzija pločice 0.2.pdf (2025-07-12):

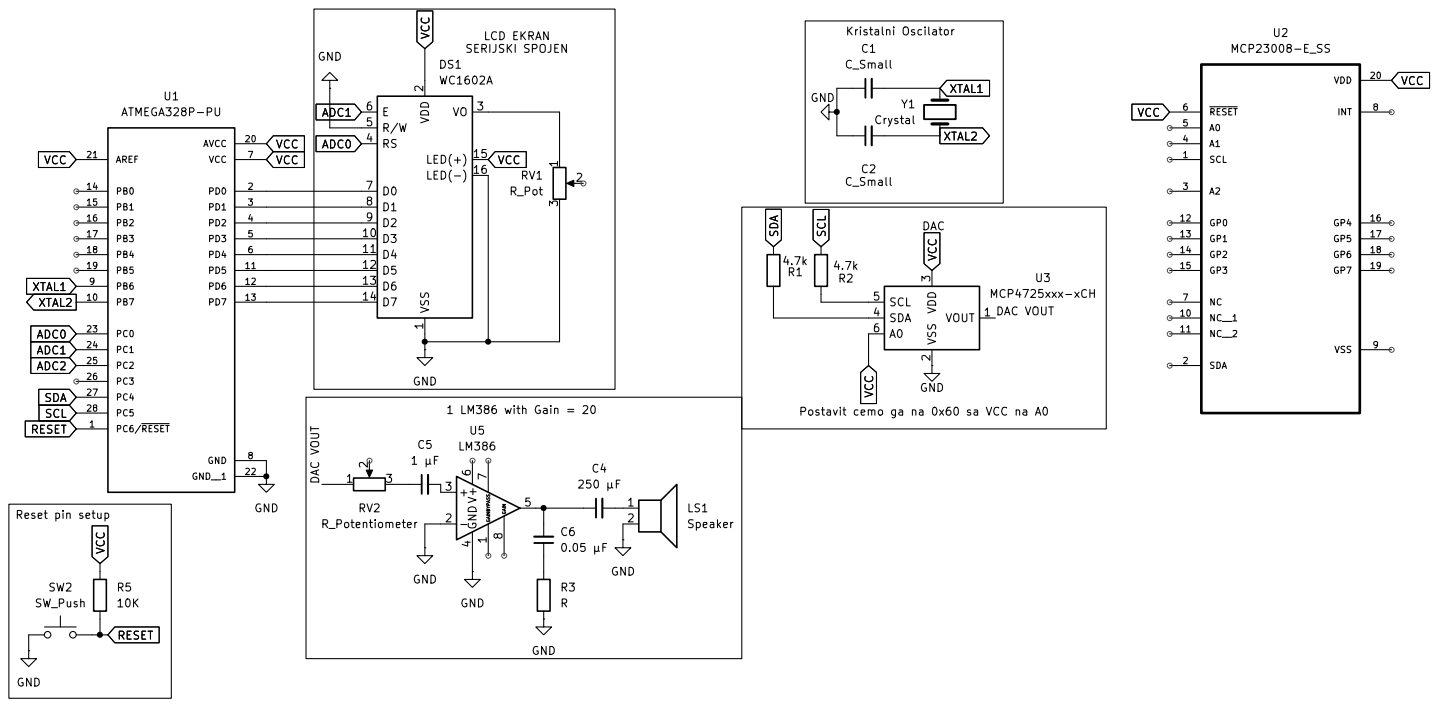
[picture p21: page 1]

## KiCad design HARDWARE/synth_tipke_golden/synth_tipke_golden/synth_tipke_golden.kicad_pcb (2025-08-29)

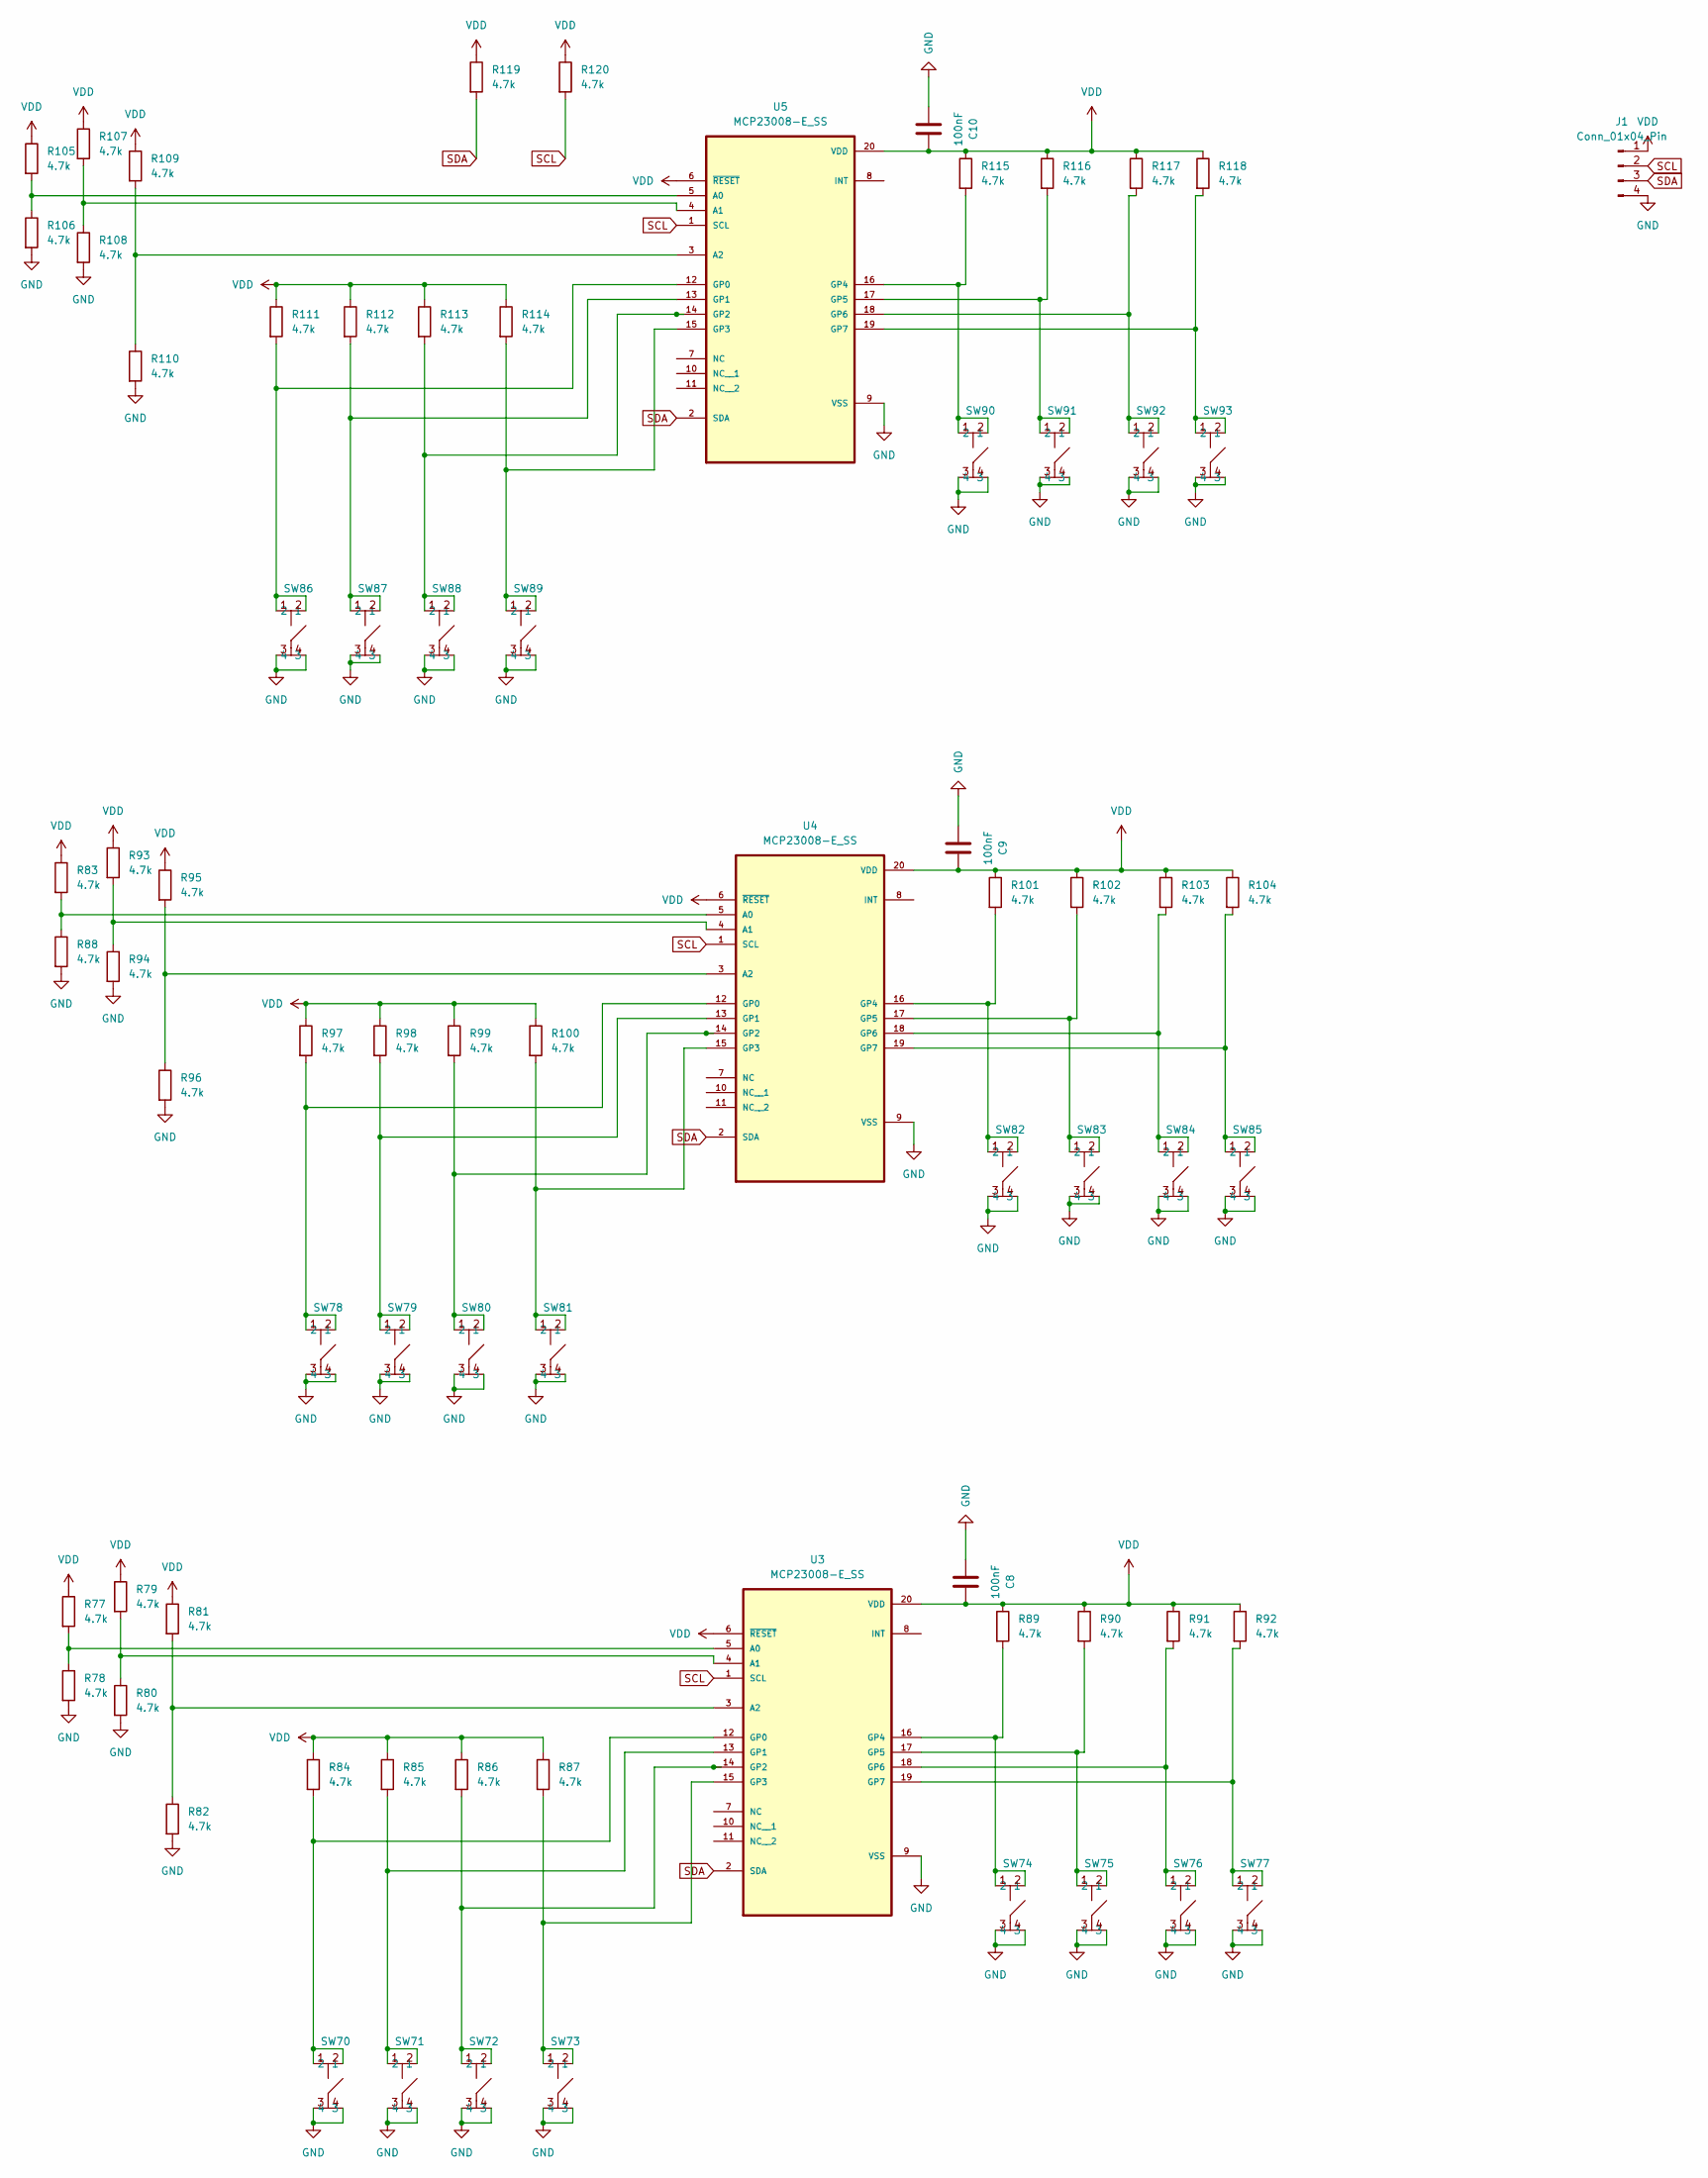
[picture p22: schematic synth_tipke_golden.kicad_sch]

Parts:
C8, C9, C10: 100nF; C_0201_0603Metric
J1: Conn_01x04_Pin; JST_EH_B4B-EH-A_1x04_P2.50mm_Vertical
R77, R78, R79, R80, R81, R82, R83, R84, R85, R86, R87, R88, R89, R90, R91, R92, R93, R94, R95, R96, R97, R98, R99, R100, R101, R102, R103, R104, R105, R106, R107, R108, R109, R110, R111, R112, R113, R114, R115, R116, R117, R118, R119, R120: 4.7k; R_0201_0603Metric
SW70, SW71, SW72, SW73, SW74, SW75, SW76, SW77, SW78, SW79, SW80, SW81, SW82, SW83, SW84, SW85, SW86, SW87, SW88, SW89, SW90, SW91, SW92, SW93: PTS530
U3, U4, U5: MCP23008-E_SS; SOP65P780X200-20N

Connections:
GND: C8.1, C9.1, C10.1, J1.4, R78.2, R80.2, R82.2, R88.2, R94.2, R96.2, R106.2, R108.2, R110.2, SW70.3, SW70.4, SW71.3, SW71.4, SW72.3, SW72.4, SW73.3, SW73.4, SW74.3, SW74.4, SW75.3, SW75.4, SW76.3, SW76.4, SW77.3, SW77.4, SW78.3, SW78.4, SW79.3, SW79.4, SW80.3, SW80.4, SW81.3, SW81.4, SW82.3, SW82.4, SW83.3, SW83.4, SW84.3, SW84.4, SW85.3, SW85.4, SW86.3, SW86.4, SW87.3, SW87.4, SW88.3, SW88.4, SW89.3, SW89.4, SW90.3, SW90.4, SW91.3, SW91.4, SW92.3, SW92.4, SW93.3, SW93.4, U3.9 (VSS), U4.9 (VSS), U5.9 (VSS)
unnamed: R77.2, R78.1, U3.5 (A0)
unnamed: R79.2, R80.1, U3.4 (A1)
unnamed: R81.2, R82.1, U3.3 (A2)
unnamed: R84.2, SW70.1, SW70.2, U3.12 (GP0)
unnamed: R85.2, SW71.1, SW71.2, U3.13 (GP1)
unnamed: R86.2, SW72.1, SW72.2, U3.14 (GP2)
unnamed: R87.2, SW73.1, SW73.2, U3.15 (GP3)
unnamed: R89.2, SW74.1, SW74.2, U3.16 (GP4)
unnamed: R90.2, SW75.1, SW75.2, U3.17 (GP5)
unnamed: R91.2, SW76.1, SW76.2, U3.18 (GP6)
unnamed: R92.2, SW77.1, SW77.2, U3.19 (GP7)
unnamed: R83.2, R88.1, U4.5 (A0)
unnamed: R93.2, R94.1, U4.4 (A1)
unnamed: R95.2, R96.1, U4.3 (A2)
unnamed: R97.2, SW78.1, SW78.2, U4.12 (GP0)
unnamed: R98.2, SW79.1, SW79.2, U4.13 (GP1)
unnamed: R99.2, SW80.1, SW80.2, U4.14 (GP2)
unnamed: R100.2, SW81.1, SW81.2, U4.15 (GP3)
unnamed: R101.2, SW82.1, SW82.2, U4.16 (GP4)
unnamed: R102.2, SW83.1, SW83.2, U4.17 (GP5)
unnamed: R103.2, SW84.1, SW84.2, U4.18 (GP6)
unnamed: R104.2, SW85.1, SW85.2, U4.19 (GP7)
unnamed: R105.2, R106.1, U5.5 (A0)
unnamed: R107.2, R108.1, U5.4 (A1)
unnamed: R109.2, R110.1, U5.3 (A2)
unnamed: R111.2, SW86.1, SW86.2, U5.12 (GP0)
unnamed: R112.2, SW87.1, SW87.2, U5.13 (GP1)
unnamed: R113.2, SW88.1, SW88.2, U5.14 (GP2)
unnamed: R114.2, SW89.1, SW89.2, U5.15 (GP3)
unnamed: R115.2, SW90.1, SW90.2, U5.16 (GP4)
unnamed: R116.2, SW91.1, SW91.2, U5.17 (GP5)
unnamed: R117.2, SW92.1, SW92.2, U5.18 (GP6)
unnamed: R118.2, SW93.1, SW93.2, U5.19 (GP7)
SCL: J1.2, R120.2, U3.1 (SCL), U4.1 (SCL), U5.1 (SCL)
SDA: J1.3, R119.2, U3.2 (SDA), U4.2 (SDA), U5.2 (SDA)
VDD: C8.2, C9.2, C10.2, J1.1, R77.1, R79.1, R81.1, R83.1, R84.1, R85.1, R86.1, R87.1, R89.1, R90.1, R91.1, R92.1, R93.1, R95.1, R97.1, R98.1, R99.1, R100.1, R101.1, R102.1, R103.1, R104.1, R105.1, R107.1, R109.1, R111.1, R112.1, R113.1, R114.1, R115.1, R116.1, R117.1, R118.1, R119.1, R120.1, U3.6 (~RESET), U3.20 (VDD), U4.6 (~RESET), U4.20 (VDD), U5.6 (~RESET), U5.20 (VDD)

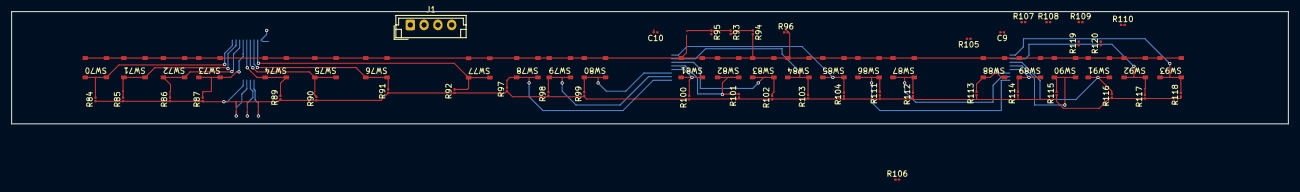
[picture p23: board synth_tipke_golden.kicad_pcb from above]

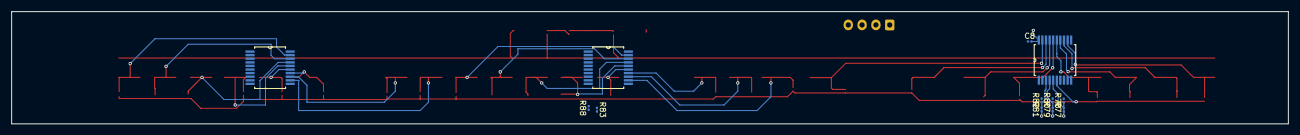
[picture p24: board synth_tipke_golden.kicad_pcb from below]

Board: 2 copper layers, 231.1 x 20.3 mm, 75 parts (12 on the bottom side), 37 nets.

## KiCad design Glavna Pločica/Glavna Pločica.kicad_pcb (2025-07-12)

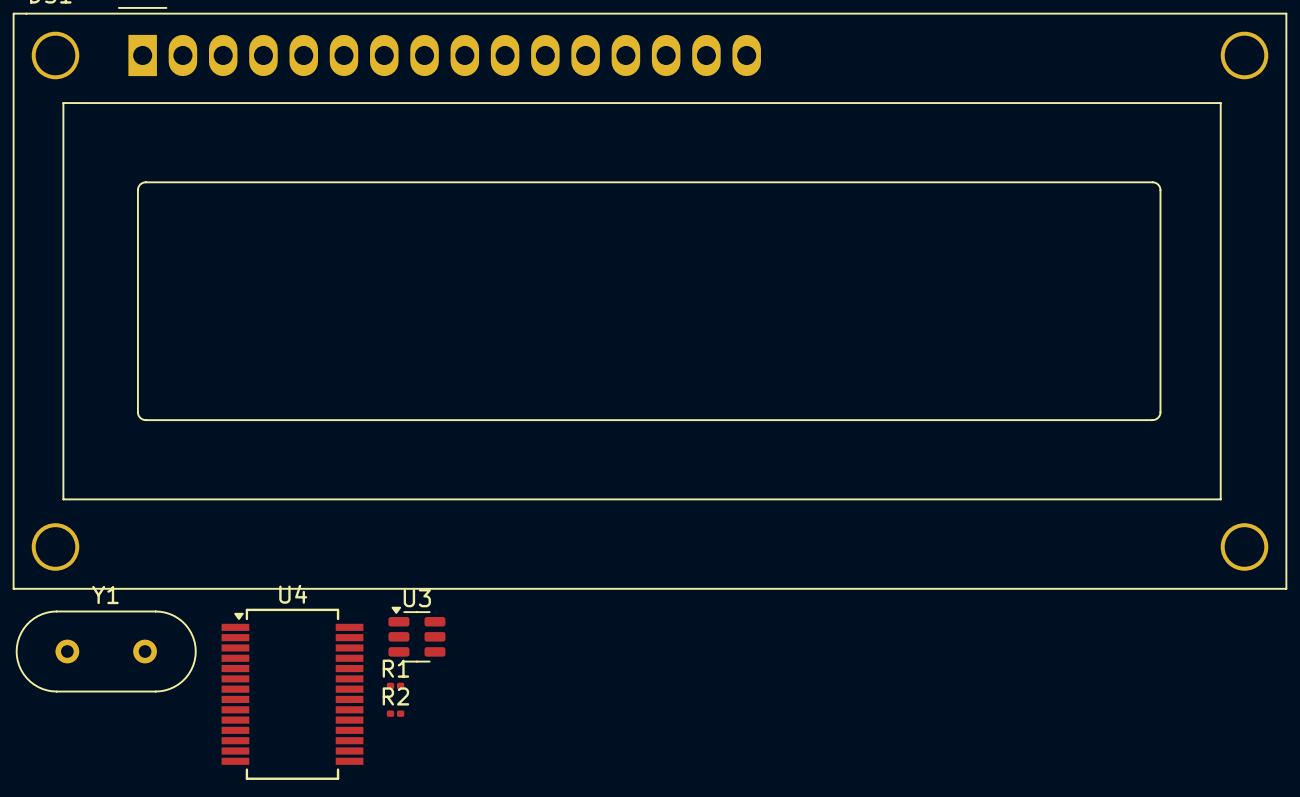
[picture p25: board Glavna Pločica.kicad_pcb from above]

Board: 2 copper layers, 6 parts (0 on the bottom side), 4 nets, no tracks yet.

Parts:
DS1: WC1602A
R1, R2: 4.7k; R_0201_0603Metric
U3: MCP4725xxx-xCH; SOT-23-6
U4: FT232RL; SSOP-28_5.3x10.2mm_P0.65mm
Y1: Crystal; Crystal_HC18-U_Vertical

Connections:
GND: DS1.1 (VSS), DS1.16 (LED(-)), U3.2 (VSS)
unnamed: R2.1, U3.5 (SCL)
unnamed: R1.1, U3.4 (SDA)
VCC: DS1.2 (VDD), DS1.3 (VO), DS1.15 (LED(+)), U3.3 (VDD), U3.6 (A0)

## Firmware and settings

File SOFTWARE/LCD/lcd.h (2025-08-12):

/*
 Naslov: MIKRORAÈUNALA - Programiranje mikrokontrolera porodice
 Atmel u programskom okruženju Atmel Studio 6
 Autori: Zoran Vrhovski, Marko Miletiæ
 
 lcd.h
 
 */ 

#include <avr/io.h>
#include <stdio.h>
#include <string.h>
#include <avr/pgmspace.h>
#include <util/delay.h>
#include "../AVR lib/AVR_lib.h"

// konfiguracija LCD displeja
#define LCD_DATA0_PORT   PORTA     	// port za 4 bitnu komunikaciju - podatkovni bit 0 	//D4
#define LCD_DATA1_PORT   PORTA     	// port za 4 bitnu komunikaciju - podatkovni bit 1 	//D5
#define LCD_DATA2_PORT   PORTA     	// port za 4 bitnu komunikaciju - podatkovni bit 2 	//D6
#define LCD_DATA3_PORT   PORTA     	// port za 4 bitnu komunikaciju - podatkovni bit 3 	//D7
#define LCD_DATA0_PIN    PA4        // pin za 4 bitnu komunikaciju - podatkovni bit 0 //D4
#define LCD_DATA1_PIN    PA5          // pin za 4 bitnu komunikaciju - podatkovni bit 1 //D5
#define LCD_DATA2_PIN    PA6         // pin za 4 bitnu komunikaciju - podatkovni bit 2 //D6
#define LCD_DATA3_PIN    PA7          // pin za 4 bitnu komunikaciju - podatkovni bit 3 //D7
#define LCD_RS_PORT      PORTA   	// port za odabir registra //RS
#define LCD_RS_PIN       PA3	      // pin  za odabir registra
#define LCD_E_PORT       PORTA     	// port za odobrenje upisa //EN
#define LCD_E_PIN        PA2        // port za odobrenje upisa

#define LCD_LINES		2			// broj vidljivih linija na LCD displeju
#define LCD_DISP_LENGTH  16    		// broj vidljivih znakova po liniji na LCD displeju

//#define LCD_RW_PORT      LCD_PORT // port za  èitanje/pisanje - mi samo pišemo //RW
//#define LCD_RW_PIN       5        // pin za  èitanje/pisanje - mi samo pišemo

// kraj konfiguracije LCD displeja




// instruction register bit positions, see HD44780U datasheet
#define LCD_CLR               	0x0    	// DB0: clear display
#define LCD_HOME              	0x1    	// DB1: return to home position
#define LCD_ENTRY_MODE        	0x2     // DB2: set entry mode
#define LCD_ENTRY_INC         	0x1     // DB1: 1=increment, 0=decrement
#define LCD_ENTRY_SHIFT       	0x0     // DB2: 1=display shift on
#define LCD_ON                	0x3     // DB3: turn lcd/cursor on
#define LCD_ON_DISPLAY        	0x2     // DB2: turn display on
#define LCD_ON_CURSOR         	0x1     // DB1: turn cursor on
#define LCD_ON_BLINK          	0x0     // DB0: blinking cursor ?
#define LCD_MOVE              	0x4     // DB4: move cursor/display
#define LCD_MOVE_DISP         	0x3     // DB3: move display (0-> cursor) ?
#define LCD_MOVE_RIGHT        	0x2     // DB2: move right (0-> left) ?
#define LCD_FUNCTION          	0x5     // DB5: function set
#define LCD_FUNCTION_8BIT     	0x4     // DB4: set 8BIT mode (0->4BIT mode)
#define LCD_FUNCTION_2LINES   	0x3     // DB3: two lines (0->one line)
#define LCD_FUNCTION_10DOTS   	0x2     // DB2: 5x10 font (0->5x7 font)
#define LCD_CGRAM             	0x6     // DB6: set CG RAM address
#define LCD_DDRAM             	0x7     // DB7: set DD RAM address
#define LCD_BUSY              	0x7     // DB7: LCD is busy

// set entry mode: display shift on/off, dec/inc cursor move direction
#define LCD_ENTRY_DEC            0x04	// display shift off, dec cursor move dir
#define LCD_ENTRY_DEC_SHIFT      0x05   // display shift on,  dec cursor move dir
#define LCD_ENTRY_INC_           0x06   // display shift off, inc cursor move dir
#define LCD_ENTRY_INC_SHIFT      0x07   // display shift on,  inc cursor move dir

// display on/off, cursor on/off, blinking char at cursor position
#define LCD_DISP_OFF             0x08   // display off
#define LCD_DISP_ON              0x0C   // display on, cursor off
#define LCD_DISP_ON_BLINK        0x0D   // display on, cursor off, blink char
#define LCD_DISP_ON_CURSOR       0x0E   // display on, cursor on
#define LCD_DISP_ON_CURSOR_BLINK 0x0F   // display on, cursor on, blink char

// move cursor/shift display
#define LCD_MOVE_CURSOR_LEFT     0x10   // move cursor left  (decrement)
#define LCD_MOVE_CURSOR_RIGHT    0x14   // move cursor right (increment)
#define LCD_MOVE_DISP_LEFT       0x18   // shift display left
#define LCD_MOVE_DISP_RIGHT      0x1C   // shift display right

// function set: set interface data length and number of display lines
#define LCD_FUNCTION_4BIT_1LINE  0x20   // 4-bit interface, single line, 5x7 dots
#define LCD_FUNCTION_4BIT_2LINES 0x38   // 4-bit interface, dual line,   5x7 dots
#define LCD_FUNCTION_8BIT_1LINE  0x30   // 8-bit interface, single line, 5x7 dots
#define LCD_FUNCTION_8BIT_2LINES 0x38   // 8-bit interface, dual line,   5x7 dots

#define LCD_START_LINE1  		 0x00   // DDRAM address of first char of line 1
#define LCD_START_LINE2  		 0x40   // DDRAM address of first char of line 2
#define LCD_START_LINE3  		 0x14   // DDRAM address of first char of line 3
#define LCD_START_LINE4  		 0x54   // DDRAM address of first char of line 4



// --- LCD Utils
// functional macros
#define lcd_e_delay()   __asm__ __volatile__( "rjmp 1f\n 1:" );
#define lcd_e_high()    LCD_E_PORT  |=  _BV(LCD_E_PIN);
#define lcd_e_low()     LCD_E_PORT  &= ~_BV(LCD_E_PIN);
#define lcd_rs_high()   LCD_RS_PORT |=  _BV(LCD_RS_PIN)
#define lcd_rs_low()    LCD_RS_PORT &= ~_BV(LCD_RS_PIN)
// address of data direction register of port x
#define LCD_DDR(x) 		(*(&x - 1))





// --- Forward functions

void EtoggleLCD(void);

//-----------------------------------------------------------------------------------------
// FUNCTION: _auxToggleE
// PURPOSE: flush channel E
void lcd_e_toggle(void);

//-----------------------------------------------------------------------------------------
// FUNCTION: lcd_write
// PURPOSE: send a character or an instruction to the LCD
void lcd_write(uint8_t data,uint8_t rs) ;

//-----------------------------------------------------------------------------------------
// FUNCTION: lcd_instr
// PURPOSE:  send an instruction to the LCD
void lcd_instr(uint8_t instr);

//-----------------------------------------------------------------------------------------
// FUNCTION: lcd_char
// PURPOSE:  send a character to the LCD
void lcd_char(uint8_t data);

//-----------------------------------------------------------------------------------------
// FUNCTION: lcd_init
// PURPOSE:  Initialize LCD to 4 bit I/O mode
void lcd_init();

//-----------------------------------------------------------------------------------------
// FUNCTION: lcd_newline
// PURPOSE:  Move cursor on specified line
void lcd_setline(uint8_t line);

extern int g_nCurrentLine;

//-----------------------------------------------------------------------------------------
// FUNCTION: lcd_print
// PURPOSE:  send a null terminated string to the LCD eg. char x[10]="hello!";
void lcd_print2(char *text);
void lcd_print(char *szFormat, ...);
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

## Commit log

2025-07-12 FIrst push
    Project initialized
    [Glavna Pločica.kicad_pcb, Glavna Pločica.kicad_sch]
2025-07-12 Second push from laptop work
    Removed RC filter
    [Glavna Pločica.kicad_sch]
2025-07-18 Promijena lm386 da moze G = 200
    Ubačena trikondenzatora, jedan na ulaz pin 6 za čišće leveliranje zvuka, jedan između 1 i 8 kako bi dobili pojačanje 200 i jedan RC filter vraćen prije zvučnika
    [Glavna Pločica.kicad_sch]
2025-07-24 I2C inicijalizacija
    [Glavna Pločica.kicad_sch]
2025-08-12 Dodan Sawtooth i lcd
    Dodani su timeri, asm nop za zastoj, dodan je lcd na portu a i izbacen usart kao testiranje
2025-08-29 Fixing names and call backs
    [atmega16Glava.kicad_sch, donja_strana.SLDPRT, donja_strana.STEP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]
